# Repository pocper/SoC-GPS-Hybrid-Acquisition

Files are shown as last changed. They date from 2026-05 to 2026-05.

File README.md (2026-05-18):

# SoC-based GPS Receiver Implementation

本專案實作了一個基於 Intel Cyclone V SoC (DE10-Nano) 平台的 GPS 接收器系統，結合了自製的 MAX2769 RF 前端模組、FPGA 硬體加速器以及 HPS 控制韌體。

## 目錄
- [SoC-based GPS Receiver Implementation](#soc-based-gps-receiver-implementation)
  - [目錄](#目錄)
  - [1. 系統架構 (System Architecture)](#1-系統架構-system-architecture)
  - [2. 目錄導覽 (Repository Structure)](#2-目錄導覽-repository-structure)
  - [3. 開發環境配置 (Development Setup)](#3-開發環境配置-development-setup)
  - [4. 硬體接線與安全須知 (Hardware Connection)](#4-硬體接線與安全須知-hardware-connection)
  - [5. 演算法架構與狀態機 (Alogorithm \& Finite State Machine)](#5-演算法架構與狀態機-alogorithm--finite-state-machine)
  - [6. 程式燒錄與執行順序 (Programming Sequence)](#6-程式燒錄與執行順序-programming-sequence)
  - [7. 運行結果與驗證 (Experimental Results)](#7-運行結果與驗證-experimental-results)
    - [7.1 測試設備 (Testing Equipment)](#71-測試設備-testing-equipment)
    - [7.2. 核心運算耗時對比 (Core Algorithm Performance)](#72-核心運算耗時對比-core-algorithm-performance)
    - [7.3 全系統定位效能與 TTFF 綜合對比 (System-Level Performance \& TTFF)](#73-全系統定位效能與-ttff-綜合對比-system-level-performance--ttff)
    - [7.4 觀測組 5 次獨立實測原始數據紀錄 (Raw Experimental Data)](#74-觀測組-5-次獨立實測原始數據紀錄-raw-experimental-data)
    - [7.5 系統定位與速度解算驗證 (PVT Verification)](#75-系統定位與速度解算驗證-pvt-verification)

## 1. 系統架構 (System Architecture)

<div align="center">
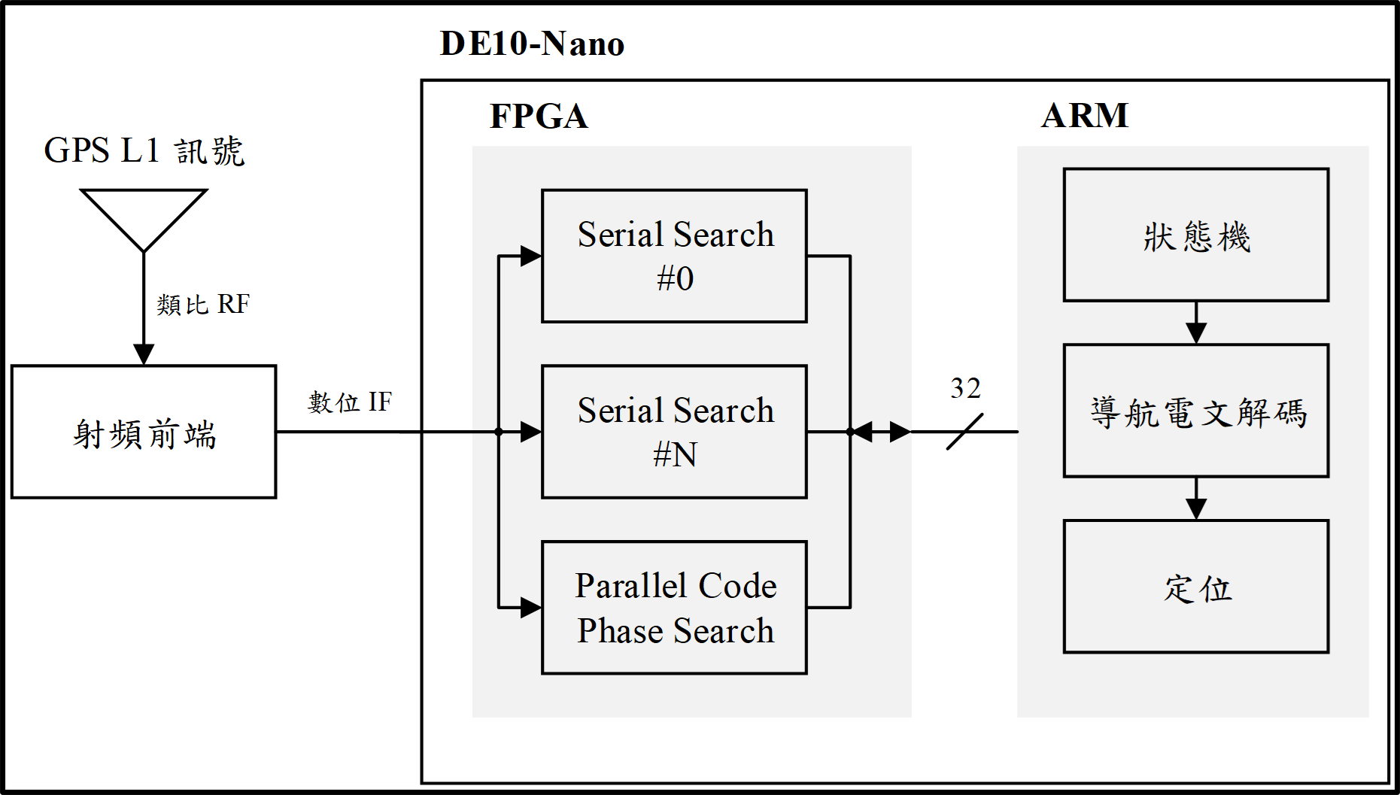
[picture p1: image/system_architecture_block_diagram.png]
系統架構
  
  <p style="margin-top: 10px;"><i>圖：系統架構圖</i></p>
</div>

本系統主要分為三大模組：
1. **RF Front-End**: 負責GPS L1訊號降採樣(Downsampling)。
2. **FPGA RTL**: 負責 Parallel Code Phase Search (PCPS) 加速。
3. **HPS Firmware**: 負責系統配置、追蹤運算與導航解算。

## 2. 目錄導覽 (Repository Structure)

1. [pcb frontend](pcb_frontend/) (Altium Designer Project)
    > 包含自製 MAX2769 RF 模組的設計檔案。
   - **硬體版本**: 目前推薦使用 **v3**。
   - **內容**: Altium Designer 專案、電路圖 (PDF)、製作與維修紀錄。

2. [rtl](rtl/) (Quartus Project)
    > 包含部署於 FPGA 端的 Verilog 原始碼與 Intel Quartus Prime 專案檔。
   - **核心模組**: 包含 Parallel Code Phase Search 與 Serial Search 之雙重訊號擷取架構。
   - **環境**: Intel Quartus Prime。
   - **重點**: 針對硬體並行化處理進行優化，減少擷取所需時間。

3. [firmware](firmware/) (Arm DS Project)
    > 負責執行於 HPS (ARM Cortex-A9) 之接收器韌體，透過 Avalon Bus 控制硬體暫存器。
   - [**hps_core/**](firmware/hps_core/)：**主要開發分支**。基於 ARM Compiler 6 (AC6) 環境開發，適用於個人電腦驗證。
   - [**hps_altera/**](firmware/hps_altera/)：**舊版相容分支**。基於 DS-5 (AC5) 環境開發，專供實驗室特定電腦驗證。

4. [matlab](matlab/) (MATLAB Project)
    > 包含 GPS 衛星訊號擷取演算法的模擬程式碼。
   - **主要功能**: 實現了平行碼相位搜尋演算法(Parallel Code Phase Search)。
   - **環境**: MATLAB。
   - **重點**: 作為演算法的功能模擬與設計標準，用於提前驗證演算法可行性，並作為後續 SoC 硬體開發時比對資料正確性的主要依據。

5. [document](docs/)
    > 存放專案相關的技術文件與操作指南。
   - [**how_to_apply_ds5.md**](docs/how_to_apply_ds5.md): **環境申請指南** (含 TSRI 資源、校園 DNS 正反查申請)。
   - [**emulator.md**](docs/emulator.md): **硬體操作手冊** (Agilent E4438C 與 Spirent GSS7000 操作流程)。
   - [**register_map.md**](docs/register_map.md): **暫存器映射表**。定義 HPS 與 FPGA  之間的通訊位址。
   - [**arm_core_initialization.md**](docs/arm_core_initialization.md): **ARM 核心與 RTOS 配置指南**。記錄 RTOS 環境下 Cortex-A9 時脈校正、GIC 映射與 RTX5 內核放寬執行緒上限之底層修正。

## 3. 開發環境配置 (Development Setup)

1. 硬體需求
   - **SoC開發板**: Terasic DE10-Nano (Cyclone V SoC)。
   - **射頻前端模組**: 自製 MAX2769 模組 (GPSR_frontend_v3)。
   - **訊號輸入源**: 
     1. **驗證配置**：經由同軸纜線連接至 Spirent GSS7000 訊號產生器。
     2. **實際配置 (未來)**：連接主動式 GPS 天線（需外接偏置電壓）。

2. 開發環境
   - **硬體開發**: Quartus Prime (建議 25.1 或以上版本) & Platform Designer。
   - **硬體/韌體函式庫**: Intel SoC EDS Embedded Development Suite (Version 20.1)。
   - **韌體開發環境**: Arm Development Studio (Version 2023.1) 或 DS-5 Altera Edition (Version 5.29.1)。
   - **即時作業系統**: CMSIS RTOS v2 (基於 Keil RTX5)。
   - **除錯終端**: PuTTY。

## 4. 硬體接線與安全須知 (Hardware Connection)

<div align="center">
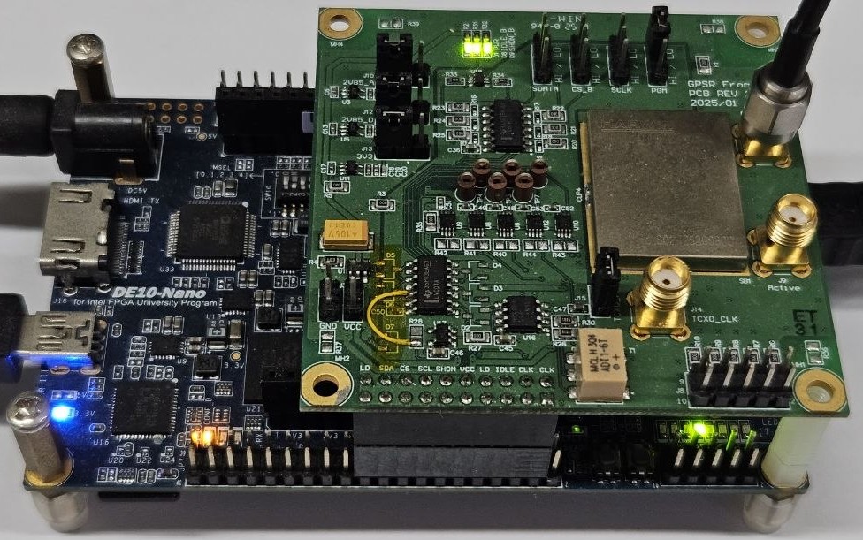
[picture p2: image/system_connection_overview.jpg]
系統接線總覽
  
  <p style="margin-top: 10px;"><i>圖：SoC GPS 接收器實驗驗證平台與硬體接線總覽</i></p>
</div>

1. **JTAG 偵錯**：將 mini-USB 連接至 DE10-Nano 的 **J13** 孔位並連接電腦 (用於 Quartus 燒錄及 DS-5 除錯)。
2. **UART 監控**：將 mini-USB 連接至 DE10-Nano 的 **J4**  孔位並連接電腦 (用於查看 HPS 端 UART Console 輸出結果)。
3. **RF 訊號輸入**：將 SMA Cable 連接至 Front-end 的 **J5** 孔位 (從GPS訊號產生器或天線提供 MAX2769 輸入訊號)。
4. **電源供應**：將 DC Power Cable(5V/2A) 連接至 DE10-Nano 的 **J14** 孔位，另一端連接插座。

> [!CAUTION]
> **重要上電順序提醒 (Critical Safety Warning)**
> 
> 在接通電源前，請務必確認上述 **1~3 項接線已全部連接穩固**。
> 
> **嚴禁在上電狀態下熱插拔 SMA 接頭**。由於上電瞬間可能產生瞬間脈衝 (Pulse) 或靜電，若此時才連接 SMA 接口，極易導致射頻前端 MAX2769 發生短路或因突波而燒毀。請遵循 **「先接線、後上電」** 的原則，拆卸時則反之。

## 5. 演算法架構與狀態機 (Alogorithm & Finite State Machine)

<div align="center">
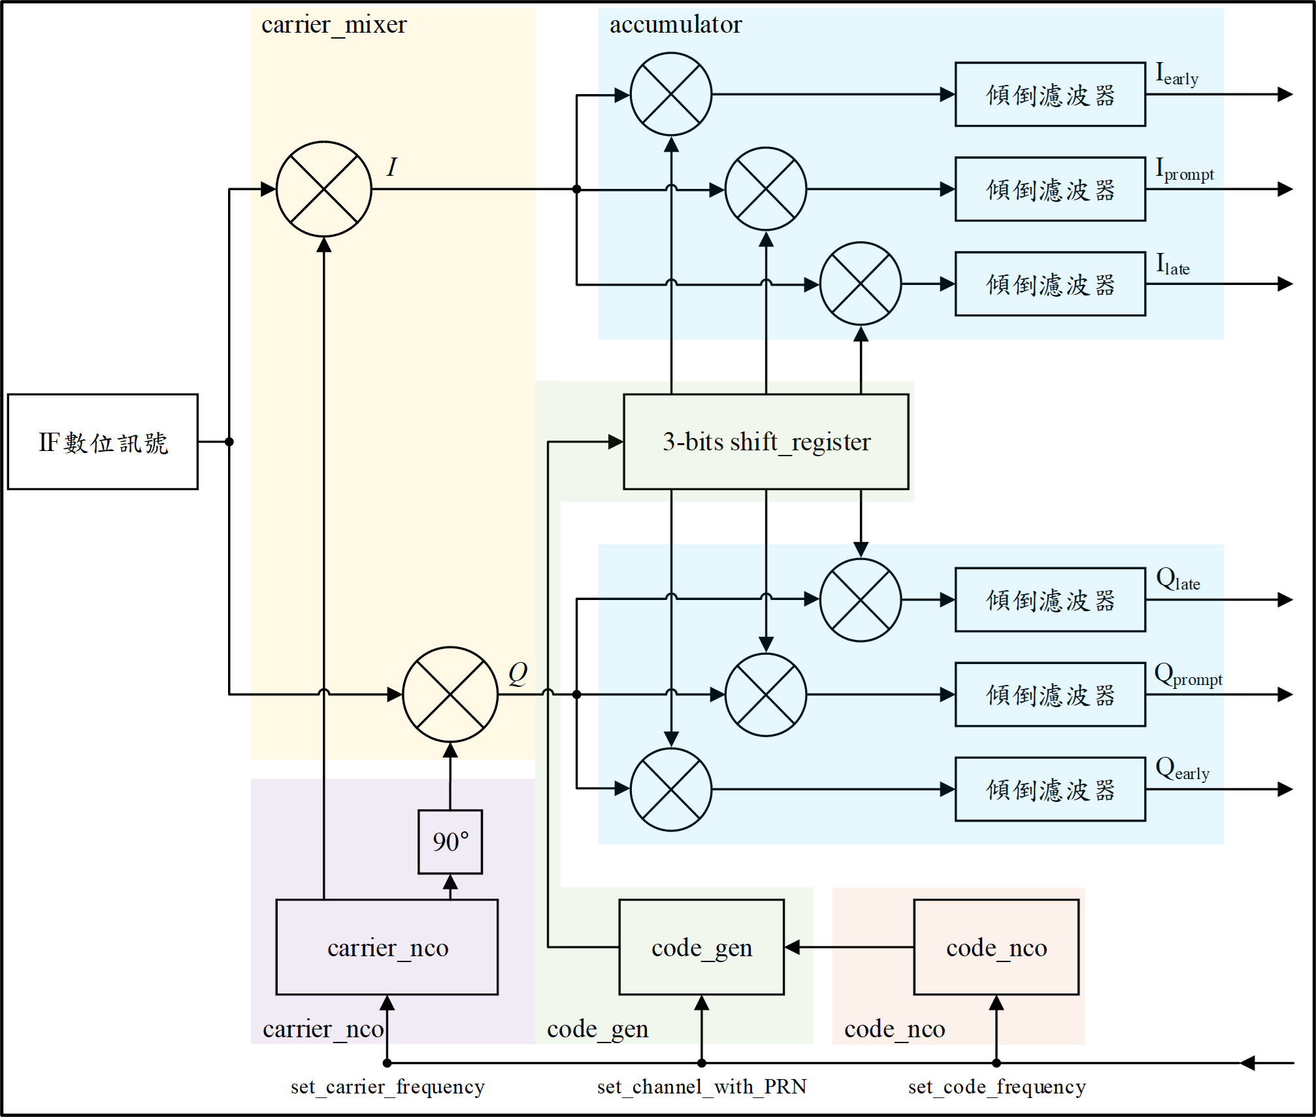
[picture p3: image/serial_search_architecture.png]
Serial Search 架構
  
  <p style="margin-top: 10px;"><i>圖：Serial Search 模組硬體架構圖</i></p>
</div>

<div align="center">
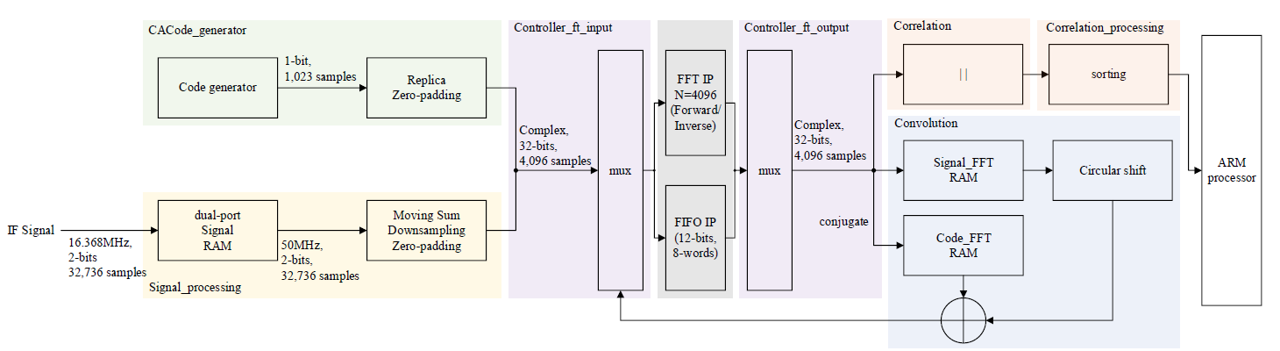
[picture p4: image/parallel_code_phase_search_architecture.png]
Parallel Code Phase Search 架構
  
  <p style="margin-top: 10px;"><i>圖：Parallel Code Phase Search 模組硬體架構圖</i></p>
</div>

<div align="center">

``` mermaid
graph LR
    classDef mainState fill:#EBF3FF,stroke:#2F80ED,stroke-width:2px,color:#000000,rx:8,ry:8;
    classDef startState fill:#1E293B,stroke:#0F172A,stroke-width:2px,color:#FFFFFF,rx:50,ry:50;

    OFF((OFF)):::startState -->|<span style='color:black;background:white;padding:2px_5px;border-radius:3px;'>Start</span>| Acquire([Acquire]):::mainState
    Acquire -->|<span style='color:black;background:white;padding:2px_5px;border-radius:3px;'>Acq. Success</span>| Confirm([Confirm]):::mainState
    Confirm -->|<span style='color:black;background:white;padding:2px_5px;border-radius:3px;'>Verify Pass</span>| Pull-In(["Pull-In"]):::mainState
    Pull-In -->|<span style='color:black;background:white;padding:2px_5px;border-radius:3px;'>Pull-In Pass</span>| Lock([Lock]):::mainState

    Acquire -->|<span style='color:black;background:white;padding:2px_5px;border-radius:3px;'>Acq. Fail</span>| OFF
    Confirm -->|<span style='color:black;background:white;padding:2px_5px;border-radius:3px;'>Verify Fail</span>| Acquire
    Pull-In -->|<span style='color:black;background:white;padding:2px_5px;border-radius:3px;'>Pull-In Fail</span>| Acquire
    Lock -->|<span style='color:black;background:white;padding:2px_5px;border-radius:3px;'>Lock Lost</span>| Pull-In
```

<p><i>圖：狀態機 - 原始架構</i></p>
</div>

<br/>

<div align="center">

``` mermaid
graph LR
    classDef mainState fill:#EBF3FF,stroke:#2F80ED,stroke-width:2px,color:#000000,rx:8,ry:8;
    classDef startState fill:#1E293B,stroke:#0F172A,stroke-width:2px,color:#FFFFFF,rx:50,ry:50;

    OFF((OFF)):::startState -->|<span style='color:black;background:white;padding:2px_5px;border-radius:3px;'>Parallel Search Done</span>| Refine([Refine]):::mainState
    Refine -->|<span style='color:black;background:white;padding:2px_5px;border-radius:3px;'>Refine Pass</span>| Pull-In(["Pull-In"]):::mainState
    Pull-In -->|<span style='color:black;background:white;padding:2px_5px;border-radius:3px;'>Pull-In Pass</span>| Lock([Lock]):::mainState

    Refine -->|<span style='color:black;background:white;padding:2px_5px;border-radius:3px;'>Refine Fail</span>| OFF
    Pull-In -->|<span style='color:black;background:white;padding:2px_5px;border-radius:3px;'>Pull-In Fail</span>| OFF
    Lock -->|<span style='color:black;background:white;padding:2px_5px;border-radius:3px;'>Lock Lost</span>| Pull-In
```
<p><i>圖：狀態機 - 混合架構</i></p>
</div>

## 6. 程式燒錄與執行順序 (Programming Sequence)

> [!IMPORTANT]
> **硬體相依性原則**：必須遵循「**先燒錄 FPGA，後燒錄 ARM**」的順序。若 FPGA 尚未配置完成便啟動 ARM 程式，CPU 會因存取未啟動的 Lightweight Bridge 實體位址而發生 Data Abort 當機。

1. **載入 FPGA 硬體邏輯 (Quartus)**：
   * 使用 **Quartus Programmer** 透過 JTAG (J13) 燒錄 `.sof` 檔案。
   * *詳細硬體編譯與 IP 配置細節請參閱 [rtl/README.md](rtl/README.md)。*

2. **執行 HPS 韌體程式 (DS-5 / Arm DS)**：
   * 根據您的環境開啟對應的整合開發環境（IDE），啟動 Debug 視窗並下載 `.axf` 執行檔至 RAM 運行：
        * **現代化環境 (Arm DS / AC6 工具鏈)** 👉 使用 **[firmware/hps_core/](firmware/hps_core/)** 專案。
        * **舊版相容環境 (DS-5 / AC5 工具鏈)** 👉 使用 **[firmware/hps_altera/](firmware/hps_altera/)** 專案。
      * *注意：首次除錯前請務必閱讀各韌體目錄下的 `README.md` 以完成 Debugger 腳本（preloader.ds）的掛載。*

3. **觀察除錯終端**：
   * 將電腦連接至 DE10-Nano 的 **J4 (USB-UART)** 埠，開啟 **PuTTY**（配置為 115200 波特率），即可即時觀測衛星搜尋等資訊。

## 7. 運行結果與驗證 (Experimental Results)

本專案透過硬體模擬器驗證接收器於不同場景下的定位效能。

### 7.1 測試設備 (Testing Equipment)
若需重現驗證結果，請參閱 **[docs/emulator.md](docs/emulator.md)** 之操作指引配置硬體環境。

| 實驗環境變數 (Parameter) | 實體軟硬體配置與參數 (Configuration Details) |
| :--- | :--- |
| **射頻訊號模擬器** | Spirent GSS7000 Multi-GNSS RF Signal Simulator |
| **測試衛星星座** | GPS L1 C/A (天空中包含 10 顆動態可見衛星) |
| **底層計時解析度** | ARM Cortex-A9 Private Timer (解析度: 1 ms) |
| **系統排程頻率** | CMSIS-RTOS v2 / Keil RTX5 (OS Tick Freuqency: 1000 Hz) |
| **統計實驗次數** | 5 次獨立重複實驗 (5 Trials per Power Level) |

### 7.2. 核心運算耗時對比 (Core Algorithm Performance)
下表展示了 SoC 平台在相同搜尋範圍下，執行不同基頻擷取演算法的純硬體運算耗時統計：

| 訊號擷取演算法 | 衛星數量 | 頻率搜索範圍 [kHz] | 總體執行時間 [ms] | 核心運算加速比 |
| :--- | :-----: | :---: | :---: | :---: |
| **直接搜尋法** <small>註1, 2</small> | 1 顆 | $0 \pm 10$ | 80,725.64 | 基準 (1.0x) |
| **碼相位平行搜尋法** | 1 顆 | $0 \pm 10$ | **4.07** | **19,834x** |
| **碼相位平行搜尋法** | 32 顆 | $0 \pm 10$ | **117.65** | **686x** |

<small>**註1**：直接搜尋法之執行時間為完整搜尋所有二維搜尋空間之最大耗時。若於搜尋空間中先行命中載波頻率及碼相位，程式會提早結束。</small>

<small>**註2**：直接搜尋法可透過在 FPGA 上配置多組實體硬體通道平行搜尋不同衛星，以降低總體執行時間。</small>

### 7.3 全系統定位效能與 TTFF 綜合對比 (System-Level Performance & TTFF)
本實驗測試共用相同之基頻硬體資源（Parallel Search 模組與 13 組序列硬體相關器通道），純粹透過 **ARM 韌體排程狀態機 (FSM) 的調度策略分流**，對比系統首次定位時間（Time To First Fix, TTFF）的實測結果：

   * **混合架構 (Parallel Code Phase Search + Serial Search)**：完整驅動 FPGA 內之 Parallel Code Phase Search 硬體加速模組進行全星座快速擷取，隨後動態將參數分派予 13 組序列硬體相關器（Serial Correlator）進行精細微調與追蹤。
   * **單一架構 (Serial Search)**：於軟體層面將 Parallel 加速器暫存器關閉，冷啟動後純依賴 13 組通道進行時域與頻域的逐點掃描。為了排除純韌體超時輪詢變因、專注比對硬體搜尋物理速度，此模式下開機**預先指派模擬器中存在的 10 顆存在衛星號碼（指定 PRN）**。

| 模擬器功率 [dBm] | 架構 | 4 顆衛星達成鎖定之耗時 [s] <br>(範圍 / 平均值) | 首次定位時間 [s] <br>(範圍 / 平均值) | **硬體搜尋加速比** |
| :---: | :---: | :---: | :---: | :---: |
| **-115** | 單一 | 19.073 ~ 28.095 (**23.902**) | 51.233 ~ 60.218 (**55.570**) | 基準 (1.0x) |
| | 混合 | 1.122 ~ 3.206 (**2.139**) | 26.085 ~ 39.069 (**31.465**) | **11.17x 加速** |
| **-120** | 單一 | 19.143 ~ 25.171 (**21.554**) | 46.075 ~ 56.133 (**50.134**) | 基準 (1.0x) |
| | 混合 | 1.152 ~ 2.253 (**1.943**) | 27.234 ~ 38.067 (**33.915**) | **11.09x 加速** |
| **-125** | 單一 | 25.234 ~ 32.026 (**29.351**) | 47.057 ~ 74.192 (**61.511**) | 基準 (1.0x) |
| | 混合 | 28.180 ~ 84.115 (**50.725**) | 80.044 ~ 156.029 (**108.885**) | **註1** |
| **-130** | 單一/混合 | — | — | **註2** |

<small>**註1**：在 `-125 dBm` 下，混合架構因頻率觀測頻寬較寬（500 Hz vs. Serial 125 Hz），致使單一頻率分度（Bin）內累積之總雜訊功率較高。在弱訊號下，真實訊號極易低於硬體偵測門檻而遭誤判，狀態機須反覆驗證，故鎖定耗時拉長。</small>

<small>**註2**：訊號功率降至 `-130 dBm` 時，在當前配置之積分時間（Parallel Code Phase Search: 2 ms / Serial: 1 ms）限制下，相關峰值已無法超越雜訊基底，故不論何種調度模式皆無法達成穩定鎖定。</small>

> [!NOTE]
> **為什麼冷啟動 (Cold Start) 解讀導航電文至少需要 18 秒？**
> * **導航電文傳輸速率**：固定只有 50 bps（每秒 50 bits）。
> * **必備資料框 (Data Frame)**：定位解算前，韌體必須完整取得子框架 (Subframe) #1、#2 與 #3。
> * **解讀時間**：每個子框架長度為 300 bits（耗時 6 秒），連續下載並解讀完這三個必備子框架（共 900 bits），**至少需要 18 秒的連續傳輸時間**（尚未包含冷啟動後捕捉前導字元以達成框架同步的時間差）。

### 7.4 觀測組 5 次獨立實測原始數據紀錄 (Raw Experimental Data)
若需核對或重現統計大表中的範圍區間，可展開下方摺疊面板檢視各組 Run 1 ~ Run 5 的詳細觀測值：

<details>
<summary><b>點擊展開：查看混合架構 5 次獨立實測詳細數據紀錄</b></summary>

| 模擬器輸出功率 [dBm] | 4 顆衛星達成鎖定之耗時 [s] <br> (Run 1 / 2 / 3 / 4 / 5) [平均值] | 首次定位時間 (TTFF) [s] <br> (Run 1 / 2 / 3 / 4 / 5) [平均值] |
| :---: | :--- | :--- |
| **-115** | 2.134 / 3.206 / 1.122 / 3.084 / 1.151 <br> **[Mean: 2.139]**  | 26.085 / 39.069 / 29.065 / 36.035 / 27.073 <br> **[Mean: 31.465]** |
| **-120** | 2.019 / 2.062 / 2.253 / 2.229 / 1.152 <br> **[Mean: 1.943]**  | 34.078 / 37.055 / 38.067 / 33.142 / 27.234 <br> **[Mean: 33.915]** |
| **-125** | 28.180 / 44.113 / 60.064 / 37.154 / 84.115 <br> **[Mean: 50.725]** | 80.044 / 98.198 / 97.006 / 113.242 / 156.029 <br> **[Mean: 108.885]** |
</details>
<br/>
<details>
<summary><b>點擊展開：查看單一架構 5 次獨立實測詳細數據紀錄</b></summary>

| 模擬器輸出功率 [dBm] | 4 顆衛星達成鎖定之耗時 [s] <br> (Run 1 / 2 / 3 / 4 / 5) [平均值] | 首次定位時間 (TTFF) [s] <br> (Run 1 / 2 / 3 / 4 / 5) [平均值] |
| :---: | :--- | :--- |
| **-115** | 23.033 / 26.176 / 19.073 / 28.095 / 23.131 <br> **[Mean: 23.902]** | 57.134 / 56.106 / 53.161 / 60.218 / 51.233 <br> **[Mean: 55.570]** |
| **-120** | 23.083 / 25.171 / 20.245 / 19.143 / 20.129 <br> **[Mean: 21.554]** | 56.133 / 46.075 / 53.237 / 48.005 / 47.221 <br> **[Mean: 50.134]** |
| **-125** | 32.026 / 25.234 / 31.201 / 27.118 / 31.176 <br> **[Mean: 29.351]** | 61.137 / 47.057 / 65.145 / 74.192 / 60.025 <br> **[Mean: 61.511]** |
</details>
<br/>

### 7.5 系統定位與速度解算驗證 (PVT Verification)

本研究在系統鎖定穩態後進行定量分析，以驗證底層基頻演算法之絕對正確性，其實驗配置與統計要點如下：

* **PVT 更新率**：**10 Hz**（每 100 ms 解算一次）。
* **統計樣本數量**：定位成功期間，連續紀錄 **1,259 筆 有效觀測樣本**。

| 效能參數 | 模擬器真實值 | 接收機實測平均值 | 實測誤差與統計指標 |
| :--- | :---: | :---: | :--- |
| **ECEF X 軸位置** | `+6378137.000 m` | `+6378135.534 m` | **1.466 m** (MAE)  |
| **ECEF Y 軸位置** | `0.000 m` | `-0.342 m` | **0.342 m** (MAE)  |
| **ECEF Z 軸位置** | `0.000 m` | `-0.245 m` | **0.245 m** (MAE)  |
| **平均定位誤差** | `0.000 m` | — | **6.492 m**  (3D 空間平均定位誤差) |
| **定位穩定度 (SD)** | `0.000 m` | — | **4.620 m** |
| **最大定位誤差** | — | — | **41.799 m** |
| **參與定位衛星顆數** | `10 顆` | `10 顆` | 訊號追蹤階段無失去鎖定 |
| **ECEF X 軸速度 ($V_x$)** | `0.000 m/s` | — | **0.633 m/s** (RMSE) |
| **ECEF Y 軸速度 ($V_y$)** | `0.000 m/s` | — | **0.245 m/s** (RMSE) |
| **ECEF Z 軸速度 ($V_z$)** | `0.000 m/s` | — | **0.331 m/s** (RMSE) |
| **平均速度誤差** | `0.000 m/s` | — | **0.756 m/s** (3D 空間平均速度誤差) |

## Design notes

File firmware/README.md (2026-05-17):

# GPSR - ARM HPS Bare-metal Implementation

本專案包含兩套針對不同編譯器與 IDE 環境所開發的 GPS 接收器 SoC 實作版本。兩者皆基於 **Intel Cyclone V SoC (DE10-Nano)** 硬體平台。

## 專案目錄說明

| 目錄名稱 | 建議環境 (IDE / Compiler) | 專案定位 | 取得方式 |
| --- | --- | --- | --- |
| **hps_core/** | **Arm DS / AC6** | **主要開發分支**。<br/>包含最新演算法、雙信號加速研究及完整專案結構。 | 須依據 `apply.md` 提出申請。 |
| **hps_altera/** | **DS-5 / AC5** | **舊版相容分支**。<br/>適用於學術單位舊型電腦環境，具備特定的 Makefile 修正機制。 | 僅限於特定配置之實驗室電腦使用。 |

---

## 核心環境差異與選擇指南

### 1. hps_core (Primary)

* **適用對象**：個人筆電或已安裝最新 **Arm Development Studio (Arm DS)** 的環境。
* **技術特點**：使用 **Arm Compiler 6 (LLVM)**，編譯效率較高且支援最新的 C 語言標準。
* **權限說明**：由於包含核心研究代碼，存取前請參考 **[how_to_apply_ds5.md](../docs/how_to_apply_ds5.md)** 完成申請程序。

### 2. hps_altera (Legacy Support)

* **適用對象**：僅能使用 **DS-5 Altera Edition (v5.29.1)** 或 **Arm Compiler 5 (AC5)** 的開發者。
* **技術特點**：針對 AC5 的語法嚴謹度進行了調校，並手動禁用了自動 Makefile 生成以避開編譯器 Bug。
* **重要備註**：本目錄不含源碼原始檔，匯入後須先執行從 `hps_core` 搬移檔案的手動同步動作。

---

## 快速上手 (Getting Started)

1. **環境確認**：檢查您的開發電腦安裝的是 **Arm DS** 還是 **DS-5 Altera Edition**。
2. **查閱文件**：
* 若進入 `hps_core`，請先閱讀該目錄下的 `README.md` 了解功能架構。
* 若進入 `hps_altera`，請務必詳閱其 `README.md` 中的 **[Step 0] 檔案複製說明**，否則專案將無法編譯。

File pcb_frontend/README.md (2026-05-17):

# Front-End (GNSS RF Module)

本文檔記錄了基於 **MAX2769** 的 GNSS 前端（Front-End）開發過程，包含從 v1 到 v3 的硬體迭代細節、已知問題與解決方案。

## 開發工具與關鍵零件

* **PCB 軟體**: Altium Designer
* **核心晶片 (MAX2769)**:
  * **v1, v3**: 使用 `MAX2769ETI/V+` (已停產)
  * **v2**: 使用 `MAX2769BETI/V+` ([Mouser 連結](https://mou.sr/4noLCAx))

* **重要提醒**: Sign/Mag 訊號是在 Clock 的上升緣變化，因此建議在 Clock 下降緣進行採樣，以確保資料穩定([datasheet - MAX2769](https://www.mouser.tw/datasheet/3/1014/1/MAX2769B.pdf))。
* 電路圖:
  * [Schematic - Version 1](./v1/GPSR_frontend_v1.pdf)
  * [Schematic - Version 2](./v2/GPSR_frontend_v2.pdf)
  * [Schematic - Version 3](./v3/GPSR_frontend_v3.pdf) 

## 版本更迭 (Version History)

* **Version 0**: 使用 MAX2769 Evaluation Boards（包含燒錄 config 板與 front-end 板）。
* **Version 1**: 依照 MAX2769 datasheet 標準電路設計。
* **Version 2**: 根據 v1 進行改版，優化屏蔽、抗干擾與時鐘同步設計。
* **Version 3**: 解決輸出電壓位準、訊號 ringing 及電源相容性問題。

| 版本 | v1 | v2 | v3 |
| :--: | :--: | :--: | :--: |
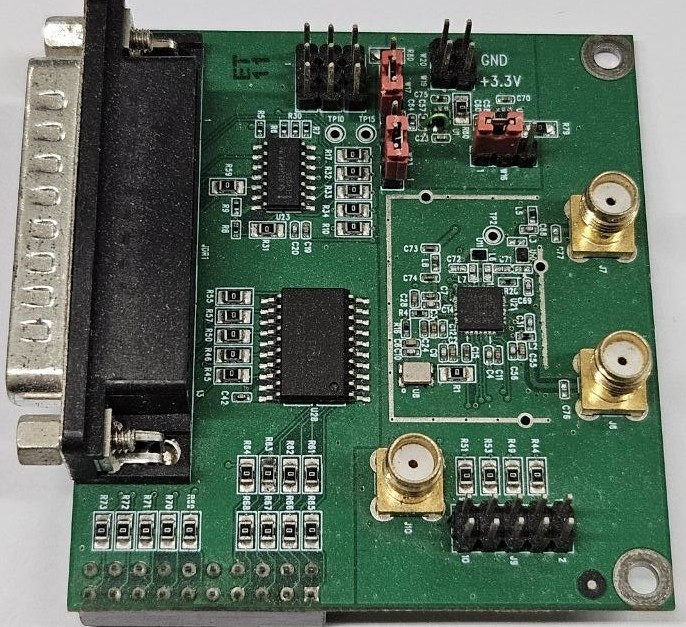
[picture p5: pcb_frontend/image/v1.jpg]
image_v1
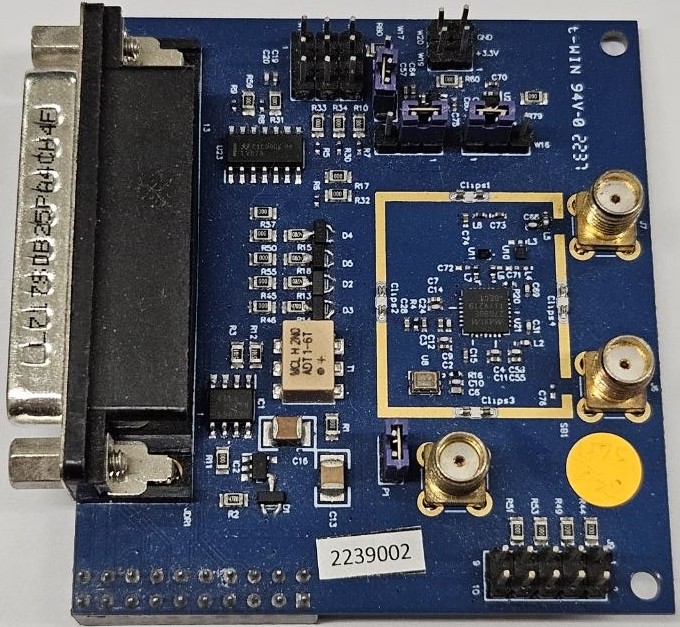
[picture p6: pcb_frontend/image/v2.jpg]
image_v2
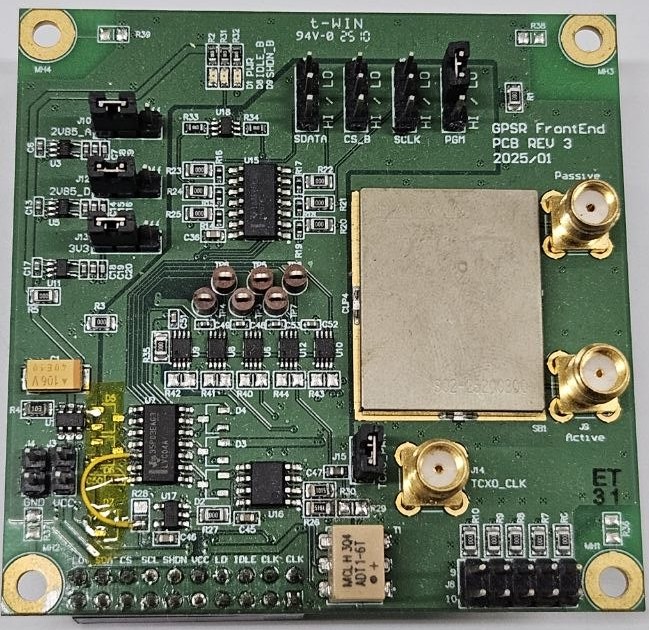
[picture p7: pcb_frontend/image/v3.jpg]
image_v3
|照片||||

## 生產與庫存記錄

* **最後更新日期**: 2026/05/11

| 版本 | v0  | v1  | v2 | v3 |
| --- | --- | --- | ---| --- |
| 原始生產數量 | 1+1 | 10  | 10 | 10 |
| 現存/可用數  | 1+1 | 2 | 10 | 9 |
| 交期 | - | - | 2022/09/16 | 2025/03/14 |

*備註：v0 係因原廠開發板配置；v1~v3 原始生產均為 10 片，數量減少源於研發過程損耗。*

---

## 相對前版本的更新 (Key Updates)

### v1 → v2

* **電路簡化**: 移除 I/Q Buffer (SN74ACT241DW)。
* **抗干擾**: 增加屏蔽框 (Shielding case)，減少外部 EMI 影響。
* **時鐘系統**:
  * TCXO 由 IT5305BE 更換為 **D32G-016.368M**。
  * 增加時鐘緩衝電路 (ADTI-6T+, MAX961ESA+, SN74LV1T34DBVRG4)。
* **訊號與保護**:
  * 更換濾波器為 SF14-1575F5UUA1。
  * 增加 GPIO 位準保護二極體 (BAT54STA)。
  * 核心晶片更換為 **MAX2769BETI+T**。

* **多天線同步設計**:
  * 增加 Header (P1) 與 SMA (J10) 設計。雙天線模式下，第二塊板需斷開 Header 並透過 J10 共享第一塊板的時鐘，以達成採樣同步。

* **特殊版本**: 10 片中透過 U11 濾波器區分：
  * **6 片 (2239000~2239005)**: GPS 頻段 (RSF-1575.420)。
  * **4 片 (2239006~2239009)**: GLONASS 頻段 (RSF-1582.400)。

### v2 → v3

* **控制介面**: 移除 D-Connector 25，改由 DE10-Nano 進行 SPI 設定。
* **電源增強**:
  * 支援 **3.3V / 5V 電壓輸入**。
  * 增加防反接保護電路 (U1A/U1B)。
  * 增加獨立 LDO (MAX8510) 穩定供電給 TCXO、Buffer 與保護電路。

* **訊號品質優化**:
  * 解決 I/Q 輸出電壓偏低 (2.85V → 3.3V) 與 ringing 問題，增加輸出 Buffer (SN74LVC1404 / SN74LVC04)。
  * 增加 GPIO 20-pin 磁珠濾波。

* **狀態顯示**: 增加指示燈 (PWR / IDLE_B / SHDN_B)，**三燈全亮**方可正常運作。

## 已知問題 (Hardware Bugs)

### v1

* PCB 原始檔案遺失。
* **電源限制**: 僅支援 3.3V 輸入，輸入 5V 會直接損毀板子。

### v2 (FAILED 版本)

* **封裝錯誤**: BAT54STA 封裝與零件不符，需人工跳線修正。
* **機構問題**: 鎖孔位置偏離，無法與 DE10-Nano 對齊。
* **接地缺陷**: MAX2769 Pin 29 (EP) 與濾波器 Pin 3 未接至 AGND，影響散熱與 EMI。
* **供電不足**: TCXO 實測僅 2.85V（應為 3.3V），導致採樣異常。
* **邏輯錯誤**: LD_OUT 未連接至 MAX2769。
* **高昂成本**: 時鐘緩衝電路零件昂貴（近 NT$ 1,000）且僅解決 CLK 訊號。

### v3

* **保護電路風險**: BAT54STA 在持續過壓時會將電流拉向 VCC/GND，可能導致整板電源軌毀損。
* **高昂成本**: 時鐘緩衝電路零件昂貴（近 NT$ 1,000）且僅解決 CLK 訊號。
* **數位失真**: GPIO 上的磁珠會導致高速數位訊號（CLK_OUT、I/Q 等）嚴重失真。

## 解決辦法 (Fixes)

### v3 必要的硬體修正步驟

1. **解決訊號失真**:
   * 將磁珠 **FB13, FB15, FB17** 更換為 **0Ω (0402)** 電阻。
   * 直接 **移除** 磁珠 FB1, FB2, FB4, FB8。

2. **邏輯與跳線**:
   * 移除電阻 **R28, R29**。
   * 跳線：連接 **U7 (SN74LVC04ADR) pin 12** 至 **R28 pin 2**。
   * C54, R45 不須焊接。

3. **成本降低建議**:
   * 若不需特定時鐘緩衝，建議移除 T1, U16, U17 及其周邊電路。

---

## GPIO 定義表
> [!NOTE]
> **注意**: v1, v2 版本請務必使用 **PIN 2 (CLK_OUT)** 作為主要時鐘源，避免使用經過 Buffer 後失真的 PIN 19。

| PIN | 變數 | 用途 | 來源地 (MAX2769) | 說明 |
| --- | --- | --- | --- | --- |
| 1 | I+ | i_sign | PIN 21 (I1_OUT) |  |
| 2 | CLK_OUT | CLK | PIN 16 (CLK_OUT) | v1, v2 主要時鐘源 |
| 3 | I- | i_mag | PIN 20 (I0_OUT) |  |
| 5 | Q+ | q_sign | PIN 17 (Q1_OUT) |  |
| 6 | IDLE_B_IN | IDLE | PIN 24 (IDLE) | 1: 工作, 0: 待機 |
| 7 | Q- | q_mag | PIN 18 (Q0_OUT) |  |
| 8 | LOCK_DET | LD | PIN 6 (LD) | 1: MAX2769 clk PLL 鎖定 |
| 12 | SHDNB_IN | SHDNE | PIN 7 (SHDNE) | 1: 開啟, 0: 關閉晶片 |
| 14 | SCLK_IN | SCLK | PIN 9 (SCLK) |  |
| 16 | CS_B_IN | CS_B | PIN 10 (CS_B) | 低電位有效 |
| 18 | D_IN | SDATA | PIN 8 (SDATA) |  |
| 19 | CLK | CLK  | PIN 16 (CLK_OUT)  | v3 主要時鐘源 |

---

## 製作與廠商資訊 (Manufacturing)

本專案硬體委託 **兆發科技 (T-Win)** 製作，包含 PCB Layout 與 SMT 上件。

* **廠商網站**: [兆發科技官方網頁](https://www.t-win.com.tw/Index-new(C).html)
* **參考費用**:
  * **v2 版本 (10片)**: 約 **NT$ 80,000 - 90,000** 級距。
  * **v3 版本 (10片)**: 約 **NT$ 110,000 - 120,000** 級距。
* **備註**: 上述價格包含 Layout、製造、零件採購與組裝。實際報價會隨晶片市場波動，詢價時請提供本專案之 Gerber 檔與 BOM 表。

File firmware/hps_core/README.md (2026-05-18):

# GPSR - ARM HPS Bare-metal Implementation
本專案實作於 **Intel Cyclone V SoC (DE10-Nano)** 平台，核心基於 **CMSIS RTOS v2** 進行任務排程，並透過 HPS 驅動 FPGA 端的 GPS 訊號擷取加速電路。

## 目錄
- [GPSR - ARM HPS Bare-metal Implementation](#gpsr---arm-hps-bare-metal-implementation)
  - [目錄](#目錄)
  - [1. 開發環境 (Prerequisites)](#1-開發環境-prerequisites)
  - [2. 專案架構與配置 (Project Structure)](#2-專案架構與配置-project-structure)
    - [核心檔案與配置](#核心檔案與配置)
    - [模組說明 (SRC / INC)](#模組說明-src--inc)
    - [軟體組件配置 (RTE Configuration)](#軟體組件配置-rte-configuration)
      - [HPS 底層暫存器與時脈校正說明](#hps-底層暫存器與時脈校正說明)
  - [3. 系統架構 (System Architecture)](#3-系統架構-system-architecture)
    - [硬體加速層 (FPGA)](#硬體加速層-fpga)
    - [軟體控制層 (CMSIS RTOS v2)](#軟體控制層-cmsis-rtos-v2)
    - [系統交互數據流 (Data Flow Diagram)](#系統交互數據流-data-flow-diagram)
  - [4. 如何執行 (Getting Started)](#4-如何執行-getting-started)
    - [Step 1: 匯入專案 (Import Project)](#step-1-匯入專案-import-project)
    - [Step 2: 編譯專案 (Build Project)](#step-2-編譯專案-build-project)
    - [Step 3: 硬體連線與除錯配置 (Debug Configuration)](#step-3-硬體連線與除錯配置-debug-configuration)
    - [Step 4: 顯示輸出資訊 (Monitoring)](#step-4-顯示輸出資訊-monitoring)
  - [5. 硬體資源配置 (Hardware Resource Allocation)](#5-硬體資源配置-hardware-resource-allocation)
    - [5.1 暫存器映射與基底位址 (Register Map \& Base Address)](#51-暫存器映射與基底位址-register-map--base-address)
    - [5.2 執行緒清單 (Thread List)](#52-執行緒清單-thread-list)
    - [5.3 中斷向量映射 (Interrupt Mapping)](#53-中斷向量映射-interrupt-mapping)
  - [6. 技術實作細節 (Implementation Details)](#6-技術實作細節-implementation-details)
    - [6.1 軟體架構與執行緒 (Software Architecture \& Threads)](#61-軟體架構與執行緒-software-architecture--threads)
    - [6.2 平行碼相位搜尋流程 (Parallel Code Phase Search Flow)](#62-平行碼相位搜尋流程-parallel-code-phase-search-flow)
    - [6.3 數據流與狀態轉移 (Data Flow \& FSM)](#63-數據流與狀態轉移-data-flow--fsm)
      - [6.3.1 狀態機比較圖 (State Machine Comparison)](#631-狀態機比較圖-state-machine-comparison)
      - [6.3.2 邏輯說明](#632-邏輯說明)
    - [6.4 訊號擷取模式配置 (Acquisition Mode Configuration)](#64-訊號擷取模式配置-acquisition-mode-configuration)
  - [7. 已知問題與解決方案 (Known Issues)](#7-已知問題與解決方案-known-issues)
  - [專案參考 (References)](#專案參考-references)
    - [硬體與底層技術手冊](#硬體與底層技術手冊)
    - [開源框架與學術文獻](#開源框架與學術文獻)

## 1. 開發環境 (Prerequisites)
* **硬體平台**: Terasic DE10-Nano (Cyclone V 5CSEBA6U23I7)。
* **開發環境**: ARM Development Studio (DS) Golden Edition (Version 2023.1)。
* **開發套件**: SoC FPGA Embedded Development Suite Standard Edition (Version 20.1)。
* **作業系統**: CMSIS RTOS v2 (基於 Keil RTX5)。
* **編譯器**: ARM Compiler 6 (AC6)。
* **終端機軟體**: PuTTY (用於透過 UART 觀察系統輸出與 HPS 狀態)。
* **硬體需求**: 需先透過 Quartus 編譯並產生 `.rbf` 檔案載入 FPGA，確保 HPS 可透過 Lightweight HPS-to-FPGA Bridge 存取暫存器。

## 2. 專案架構與配置 (Project Structure)

本專案採模組化設計，將硬體底層驅動、GPS 核心演算法與 RTOS 系統配置分離。

### 核心檔案與配置

* **`DE10_serial_parallel/main.c`**: 程式進入點，負責 線程(Threads)初始化、硬體周邊配置及啟動 CMSIS RTOS v2 核心任務。
* **`DE10_serial_parallel/DE10_serial_parallel.rteconfig`**: ARM Development Studio 的運行環境配置文件，定義組件相依性。
* **`DE10_serial_parallel/config_hardware/`**: 存放偵錯配置檔 (`.launch`)，記錄 JTAG 連線參數與應用程式下載設定。
* **`bootloader/preloader.ds`**: ARM DS 除錯腳本，用於引導硬體初始化。該腳本會加載並執行同目錄下的 **`u-boot-spl`**，完成 HPS 側的 UART、DDR 記憶體及多功能引腳 (I/O Multiplexing) 的初始化，確保應用程式能正確下載至 RAM 運行。

### 模組說明 (SRC / INC)

檔案依功能劃分為以下四大模組：

| 模組類別 | 包含檔案 (實作/標頭檔) | 說明 |
| --- | --- | --- |
| **系統與通訊** | `uart.c`, `display.c`, `message.c` | 負責 HPS UART 偵錯輸出、數據格式封裝及資訊顯示。 |
| **硬體驅動層** | `max2769.c`, `altera_avalon_spi.c`, `parallel_search.c`  | 處理 RF 前端 (MAX2769) 配置、Avalon Bus 通訊及**平行搜尋硬體加速器**控制。 |
| **GPS 核心演算法** | `tracking.c`, `measure.c`, `ephemeris.c`, `position.c` | 實現衛星信號追蹤、虛擬距離測量、星曆解析及定位運算 (PVT)。 |
| **導航計算工具** | `DOP.c`, `pseudorange.c`, `allocate.c`, `time.c` | 處理幾何精度因子計算、時間同步及衛星通道分配邏輯。 |

### 軟體組件配置 (RTE Configuration)

匯入專案後，請雙擊打開 `.rteconfig` 檔案，確保 **Manage Run-Time Environment** 視窗中已正確勾選以下組件，這對於 **ARM Compiler 6 (AC6)** 的編譯至關重要：

| 類別 (Category) | 組件名稱 (Component) | 變體 (Variant) | 實測版本 (Version) | 說明 |
| --- | --- | --- | --- | --- |
| **ARMCA9** | - | - | **1.1.0** | 提供 Cortex-A9 核心基礎定義。 |
| **CMSIS** | **CORE** | - | **6.1.0** | 提供 Cortex-A9 核心基礎定義。 |
| **CMSIS** | **OS Tick (API) -> Private Timer** | - | **1.0.2** | 提供 RTOS 系統時間，確保任務切換與延時運算之精準度。 |
| **CMSIS** | **RTOS2 (API) -> Keil RTX5** | **Source** | **5.9.0** | 核心任務調度器，負責多執行緒並行運作。 |
| **CMSIS-Compiler** | **STDIN/STDOUT (API) -> Custom** | - | **1.1.0** | 將 `printf` 重新導向至 `uart.c`。 |
| **Device** | **IRQ Controller (API) -> GIC** | - | **1.2.0** | 管理來自 FPGA 端之 **FPGA_IRQ0/1** 中斷。 |
| **Device** | **Startup** | - | **1.2.0** | 包含啟動引導、Scatter file 與 **MMU 配置**。 |

#### HPS 底層暫存器與時脈校正說明

本專案在 ARM DS / DS-5 環境下，已針對 CMSIS 產生的預設 `ARMCA9` 核心配置進行了關鍵修正（包含 GIC/Timer 實體位址重對映、925 MHz 4分頻時脈校正、關閉 MMU 以及鎖定 `-O0` 編譯優化）。

* **完整相容性原理與核對清單**：請參閱詳細技術指南 [docs/arm_core_initialization.md](../../docs/arm_core_initialization.md)
* *註：相關修正已完好儲存於本專案的 `INC/` 與設定檔中，匯入後自動覆蓋預設值，此文件僅供原理核對使用。*

## 3. 系統架構 (System Architecture)
本系統將 GPS 接收器的處理邏輯分為「即時韌體控制」與「硬體運算加速」兩大部分：

### 硬體加速層 (FPGA)

* **Serial Search**: 負責多通道的關聯運算（Correlators）與衛星追蹤。
* **Parallel Code Phase Search**: 負責快速擷取衛星訊號，大幅縮短首次定位時間 (TTFF)。
* **MAX2769 SPI 控制**: 負責 RF 前端參數設定。

### 軟體控制層 (CMSIS RTOS v2)

* **Task Scheduling**: 包含衛星搜尋任務、追蹤環路任務、以及數據遙測傳輸任務。
* **Event Handling**: 利用 RTOS Event Flags 或 Semaphores 響應硬體中斷。

### 系統交互數據流 (Data Flow Diagram)
本專案之軟硬體交互邏輯參考自經典的開源導航專案 Namuru GPS，並針對 Cyclone V HPS 進行了移植與優化：

<div align="center">
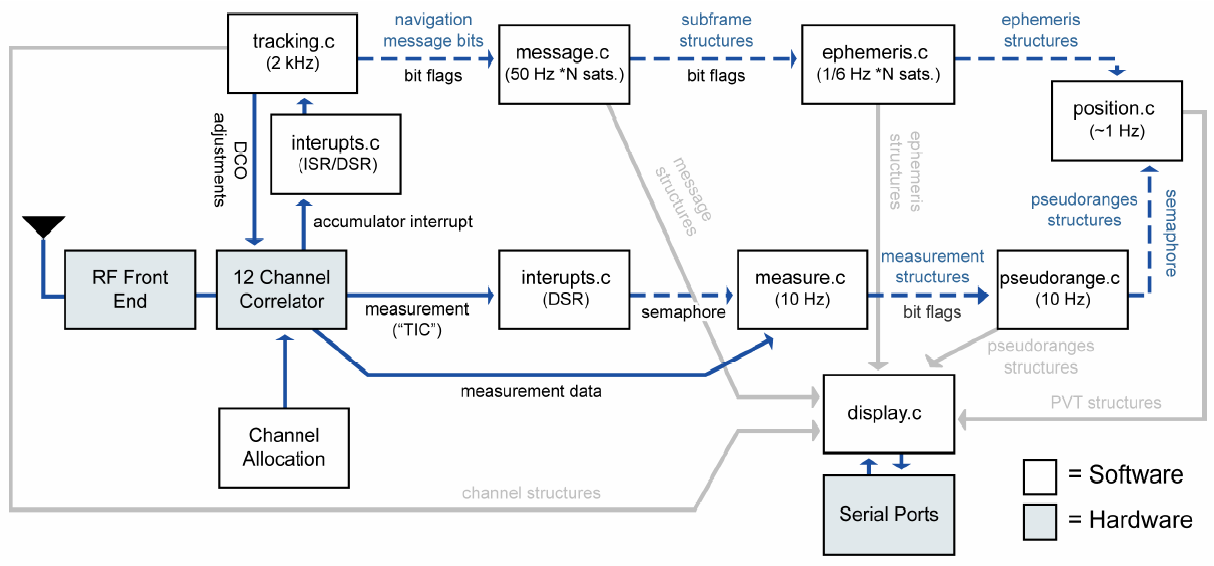
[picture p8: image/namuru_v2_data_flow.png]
Namuru V2 數據流圖
  
  <p><i>圖：Namuru V2 框架之數據流圖（圖片來源：<a href="https://www.semanticscholar.org/paper/The-Namuru-V2-open-source-GNSS-receiver-project-Mumford-Akos/fdfd5889722f786af1faafd68cfd5bef9aa55d25" target="_blank">The Namuru V2 Project</a>）</i></p>
</div>

## 4. 如何執行 (Getting Started)
本節說明如何將專案匯入 **ARM Development Studio**、編譯並透過 **USB-Blaster II** 進行硬體偵錯。

### Step 1: 匯入專案 (Import Project)

1. 啟動 **ARM Development Studio** (Golden Edition)。
2. 點選選單 `File` -> `Switch Workspace` -> `firmware/hps_core`。
3. 點選選單 `File` -> `Import...`。
4. 選擇 `General` -> `Existing Projects into Workspace`，並點選 `Next`。
5. 在 `Select root directory` 中點選 `Browse..`，路徑切換至 `firmware/hps_core/DE10_serial_parallel` 目錄後點選 `選擇資料夾`。
6. 在 `Projects` 清單中勾選 `DE10_serial_parallel`，最後點選 `Finish`。

### Step 2: 編譯專案 (Build Project)

1. 點選選單 `Project` -> `Build All`。
2. **編譯檢查**：
   * 出現 **Warnings** 通常為編譯器優化建議，尚可接受。
   * 若出現 **Errors** 則代表 `.axf` 執行檔未成功生成，請檢查 Include 路徑或 CMSIS 庫配置。

### Step 3: 硬體連線與除錯配置 (Debug Configuration)

1. **硬體連結**：
   * 使用一條 **Mini USB 線** 連接 DE10-Nano 上的 **USB-Blaster II 埠** (J13) 與開發電腦。
   * 無需外接額外的偵錯器硬體，該連線同時提供 JTAG 偵錯與 UART 通訊功能。

2. **硬體檢查**：
   * **指撥開關 (MSEL)**：請確保DE10-Nano 上的 **MSEL[4:0]** 開關設定為 `01010` (FPP 模式)以允許 HPS 透過 FPGA Manager 配置硬體。
   * **FPGA 載入狀態**：在啟動 DS 偵錯前，請務必透過 Quartus Programmer 載入對應的 `.rbf` 檔案。
    > [!IMPORTANT]
    > * **重要安全機制**：若 FPGA 未載入或 Bridge 未開啟，HPS 存取 `0xFF200000` 位址空間時會導致 **Data Abort (資料終止異常)**，造成系統當機。

3. **偵錯配置**：
   * 在 `Debug Control` 視窗點選 `Connect with an existing Config...` 並選擇 `config_hardware`。
   * **若無法連線 (Unable to connect)**，請手動校對設定：
     * **Connection**: 選擇 `Intel SoC FPGA` -> `Cyclone V SoC (Dual Core)` -> `Bare Metal Debug` -> `Debug Cortex-A9_0`。
     * **Bare Metal Debug**: 確保顯示 `DE-SoC on localhost [USB-1]`。
     * **Files 標籤頁**: 檢查 `Application on host to download` 是否指向 `${workspace_loc:/DE10_serial_parallel/Debug/DE10_serial_parallel.axf}` 並勾選 `Load symbols`。
     * **Debugger 標籤頁**: 在 `Run control` 選擇 `Debug from symbol` 並填入 `main`；同時確保 `Run target initialization debugger script` 已載入 `${workspace_loc:/DE10_serial_parallel/bootloader/preloader.ds}` 以完成 HPS 初始化。
     * **OS Awareness 標籤頁**: 在 `Select OS awareness` 選擇 `Keil CMSIS-RTOS RTX`，以利在偵錯時觀察 **RTOS v2** 任務狀態。

4. **開始偵錯與執行**：
   * 確認上述設定無誤後，點選視窗右下角的 **`Debug`** 按鈕。
   * **下載與掛載**：IDE 將會開始燒錄 `.axf` 執行檔至 HPS 記憶體，並根據設定自動停在 `main` 函式的起始點。

5. **啟動運行**：在 `Debug Control` 視窗點選 `Continue (F8)`，系統才會正式進入 main 並啟動核心調度。

### Step 4: 顯示輸出資訊 (Monitoring)

1. **確認 COM Port 編號**：
   * 在 Windows 任務欄的「開始」圖示點選右鍵，選擇 **「裝置管理員 (Device Manager)」**。
   * 展開 **「連接埠 (COM 和 LPT)」** 項目。
   * 尋找名稱含有 **`Altera USB-Blaster II`** 或 **`USB Serial Port`** 的項目，並記下其後方的編號（例如：`COM3`）。

2. **開啟並配置 PuTTY**：
   * 啟動 **PuTTY** 程式。
   * 在 `Connection type` 選擇 **`Serial`**。
   * 在 `Serial line` 欄位輸入剛才確認的編號（如 `COM3`）。
   * 在 `Speed` 欄位輸入 **`115200`** 。
   * 點選 **`Open`** 開啟終端機視窗。

3. **開始執行與觀測**：
   * 回到 ARM DS 偵錯界面，點選 `Debug Control` 中的 **`Continue (F8)`**。
   * 此時系統正式啟動，你可以在 PuTTY 視窗中即時觀測到 GPS 接收器的初始化資訊、衛星追蹤狀態以及經緯度等運算數據。

## 5. 硬體資源配置 (Hardware Resource Allocation)

本專案透過 **Lightweight HPS-to-FPGA Bridge** 存取 FPGA 端的自定義模組，並透過 **GIC (Generic Interrupt Controller)** 進行即時事件管理。

### 5.1 暫存器映射與基底位址 (Register Map & Base Address)

所有硬體模組均掛載於 HPS 物理位址 `0xFF200000` 開始的空間。

| 模組名稱 | 系統基底位址 (System Base) | 內部偏移量 (Offset) | 說明 |
| --- | --- | --- | --- |
| **Serial Search** | `0xFF200000` | `0x000` | 13 個衛星追蹤通道與系統時序控制。 |
| **Parallel Search** | `0xFF200400` | `0x400` | 平行碼相位搜尋加速模組 (Acquisition)。 |
| **MAX2769** | `0xFF200820` | `0x820` | 射頻前端 SPI 控制暫存器。 |

詳細的定義與暫存器描述請參考：  
👉 [詳細暫存器定義說明書](../../docs/register_map.md)

### 5.2 執行緒清單 (Thread List)

| 線程 (Thread) | 優先度 (Priority) | 功能說明 |
| --- | --- | --- |
| **`measure_thread`** | `osPriorityRealtime` | 負責計算 PVT (Position, Velocity, Time) 解算。 |
| **`message_thread`** | `osPriorityHigh` | 負責導航電文子框 (Subframe #1~#5) 的內容解析。 |
| **`parallel_search_thread`** | `osPriorityAboveNormal` | 觸發 Parallel Search 硬體加速模組並讀取解算結果。  |
| **`allocate_thread`** | `osPriorityAboveNormal` | 分配與初始化 Serial Search 通道參數。 |
| **`display_thread`** | `osPriorityNormal` | 透過 UART0 即時顯示系統狀態與衛星資訊。 |

### 5.3 中斷向量映射 (Interrupt Mapping)

中斷訊號直接連接至 HPS GIC，驅動對應的處理函數與事件轉發。

| 中斷來源 (Interrupt) | GIC ID | 處理函數 (Handler) | 功能說明 |
| --- | --- | --- | --- |
| **FPGA_IRQ0** | 72 | `tracking_IRQ` | 每 0.5ms 由 FPGA 發送，更新各通道追蹤狀態與參數。  |
| **FPGA_IRQ1** | 73 | `parallel_search_IRQ` | Parallel Search 運算完成時觸發，讀取硬體運算結果。 |
| **UART0_IRQ** | 194 | `set_display_command` | 鍵盤敲擊觸發 (RX IRQ)，讀取使用者輸入字元。 |

## 6. 技術實作細節 (Implementation Details)

### 6.1 軟體架構與執行緒 (Software Architecture & Threads)

本專案基於 **CMSIS RTOS v2** 實現多執行緒並行處理，主要執行緒分配如下：

```c
// 核心任務初始化
allocate_thread_id        = osThreadNew(allocate_thread, ...);        // 衛星通道分配與狀態管理
parallel_search_thread_id = osThreadNew(parallel_search_thread, ...); // 平行搜尋模組調度
message_thread_id         = osThreadNew(message_thread, ...);         // 導航電文解析 (50 Hz)
measure_thread_id         = osThreadNew(measure_thread, ...);         // 虛擬距離測量 (10 Hz)
display_thread_id         = osThreadNew(display_thread, ...);         // 終端機資訊輸出
```

### 6.2 平行碼相位搜尋流程 (Parallel Code Phase Search Flow)

為縮短擷取時間，系統採用「混合式搜尋架構」。當 `allocate_thread` 偵測到通道閒置時，會透過 `osThreadFlags` 通知 `parallel_search_thread` 啟動硬體加速器。

* **執行效率對比**：相較於直接搜尋法（需時約 80,725 ms），本專案的平行搜尋演算法僅需 **4.07 ms** 即可完成單顆衛星搜尋，效能提升顯著。
* **同步機制 (Slew Control)**：在取得碼相位（Code Phase）後，韌體會計算理論 Slew 值並調整衛星通道 NCO，確保硬體追蹤通道能精準鎖定訊號。

| 訊號擷取演算法 | 衛星數量 | 搜尋範圍 | 執行時間 | 效能提升 |
| --- | --- | --- | --- | --- |
| **Serial Search** | 1 顆 | $\pm 10$ kHz | ~80,725 ms | 基準 |
| **Parallel Code Phase Search** | 1 顆 | $\pm 10$ kHz | **4.07 ms** | **~19,800x** |

### 6.3 數據流與狀態轉移 (Data Flow & FSM)

本專案優化了衛星通道的狀態機轉移邏輯，將原本序列搜尋（Serial Search）所需的擷取與確認階段，簡化為由硬體加速器引導的 `Refine` 階段。

#### 6.3.1 狀態機比較圖 (State Machine Comparison)
``` mermaid
stateDiagram-v2
    direction LR

    state "原始架構 (Serial Search Only)" as original {
        direction LR
        OFF_orig: OFF
        Acquire: Acquire (1ms/20ms)
        Confirm: Confirm
        PullIn_orig: Pull-in
        Lock_orig: Lock

        OFF_orig --> Acquire
        Acquire --> Confirm
        Confirm --> PullIn_orig
        PullIn_orig --> Lock_orig
        
        Confirm --> OFF_orig: Fail
        PullIn_orig --> OFF_orig: Lost
    }

    state "混合架構 (Serial + Parallel Search)" as hybrid {
        direction LR
        OFF_hyb: OFF
        Refine: Refine (Hardware Guided)
        PullIn_hyb: Pull-in
        Lock_hyb: Lock

        OFF_hyb --> Refine: Parallel Search Done
        Refine --> PullIn_hyb
        PullIn_hyb --> Lock_hyb
        
        Refine --> OFF_hyb: Fail
        PullIn_hyb --> OFF_hyb: Lost
    }
```

#### 6.3.2 邏輯說明

* **原始架構**：必須經歷 `Acquire`（擷取）與 `Confirm`（確認）階段，這在 Serial Search中是透過不斷位移碼相位與載波頻率來實現的，也是最耗時的部分。
* **混合架構 (本專案)**：新增了 **`Refine`** 狀態。 由於 **Parallel Code Phase Search** 模組已經提供了精確的初始相位與頻率偏移，韌體僅需在 `Refine` 階段進行最後的窄頻對齊，即可直接跳轉至 `Pull-in` 鎖定，取代了訊號擷取耗時的搜尋流程。

### 6.4 訊號擷取模式配置 (Acquisition Mode Configuration)

本專案之基頻硬體搜尋策略支援在編譯時期（Compile-time）進行靜態配置。透過修改硬體描述層的巨集定義，即可自由切換 `Serial Search` 或是 `Hybrid (Parallel Code Phase Search + Serial Search)`。

* **檔案位置**：`firmware/hps_core/DE10_serial_parallel/INC/namuru.h`
* **巨集定義切換**：透過註解控制以下巨集定義即可完成切換：

    ```c
    // Hybrid mode (Parallel Code Phase Search + Serial Search)
    #define ACQ_MODE_SYSTEM ACQ_MODE_HYBRID

    // Only Serial Search
    // #define ACQ_MODE_SYSTEM ACQ_MODE_SERIAL
    ```

## 7. 已知問題與解決方案 (Known Issues)
* **Linker Warning L6329W**: 
  - 現象：`Pattern *(correlation_section) only matches removed unused sections.` / `Pattern *(data_CDC_section) only matches removed unused sections.`
  - 原因：Scatter file 預留了資料交換區塊，但目前的實作尚未宣告對應變數。
  - 影響：不影響功能，可忽略或在 .sct 檔中註解。

* **GPS 週數翻轉物理限制 (GPS Week Rollover Handling)**:
  - **位置**：`ephemeris.c` 中的 `process_subframe1()` 函式。
  - **現象**：GPS 導航電文第一子框架（Subframe 1）中的週數（Week Number）欄位僅有 10 bits，其物理上限為 $2^{10} = 1024$ 週（約 19.7 年），期滿即觸發 Rollover 清零。目前底層舊有常式採用硬編碼（Hard-coded）直接加 1024 週的方式來盲猜當前世紀時間。
  - **影響與修正建議**：此機制會導致全系統在面臨 **Rollover #2（2019/04/06）** 之後的現代真實時間場景時產生解算誤差（例如將目前時間誤判為 2000 ~ 2019 年之間）。若需將本系統部署於真實空域或最新模擬器場景中進行長時間量測，**請務必修改該處常式，根據當前真實年份將模數偏置（Offset）調整為 2048 週**，以利後端 PVT 矩陣導出正確的 UTC 時間戳記。

## 專案參考 (References)

### 硬體與底層技術手冊

* **[Intel Cyclone V HPS Address Map](https://www.intel.com/content/www/us/en/programmable/hps/cyclone-v/hps.html)**: 詳列 HPS 暫存器定義、中斷 ID 以及 **Lightweight HPS-to-FPGA Bridge** 的物理位址映射。
* **[Terasic DE10-Nano User Manual](https://www.terasic.com.tw/cgi-bin/page/archive.pl?Language=English&No=1046&PartNo=4)**: 提供開發板電路架構、USB-Blaster II 介面及周邊 Pinout 說明。
* **[CMSIS RTOS v2 Documentation](https://arm-software.github.io/CMSIS_5/RTOS2/html/index.html)**: 關於 `osThreadNew`、`osThreadFlags` 等 API 使用規範之官方文件。

### 開源框架與學術文獻

* **[Namuru V2 GNSS Project Reference](https://unsworks.unsw.edu.au/bitstreams/432f137e-324f-4682-beb5-ab08175aabf0/download)**: 本專案之軟體框架（如任務優先權、數據流結構）高度參考此開源專案。該報告由新南威爾斯大學 (UNSW) 發表，提供 12 Channel Correlator 與導航電文解析之核心邏輯。

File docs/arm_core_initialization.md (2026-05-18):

# Cyclone V HPS 底層暫存器與時脈校正指南

本文件紀錄了本專案在 ARM DS 或 DS-5 環境下，為了正確驅動 CMSIS RTOS v2 (Keil RTX5) 與 HPS 底層周邊，針對 ARMCA9 核心配置進行關鍵的底層修正。

> [!NOTE]
> 本專案已將所有修正完畢的標頭檔與設定直接納入版本控制。當您匯入專案時，正確的硬體參數與暫存器位址會自動覆蓋 (Override) 系統預設值，一般情況下您無需手動修改任何程式碼。本文件僅供環境核對與底層時脈/硬體原理解析使用。

## 目錄
- [Cyclone V HPS 底層暫存器與時脈校正指南](#cyclone-v-hps-底層暫存器與時脈校正指南)
  - [目錄](#目錄)
  - [核心修正與架構核對清單](#核心修正與架構核對清單)
    - [1. GIC 與 Private Timer 實體硬體位址修正](#1-gic-與-private-timer-實體硬體位址修正)
    - [2. 主頻時脈校正與 Private Timer 分頻計算](#2-主頻時脈校正與-private-timer-分頻計算)
    - [3. 關閉虛擬記憶體管理單元 (Disable MMU)](#3-關閉虛擬記憶體管理單元-disable-mmu)
    - [4. 記憶體基底重映射 (Memory Base Remapping)](#4-記憶體基底重映射-memory-base-remapping)
    - [5. 編譯優化等級配置說明 (Optimization Level)](#5-編譯優化等級配置說明-optimization-level)
    - [6. 記憶體佈局與核心區段配置 (Scatter File Configuration)](#6-記憶體佈局與核心區段配置-scatter-file-configuration)
    - [7. RTOS 核心內核配置與執行緒上限核對 (RTX Kernel Configuration)](#7-rtos-核心內核配置與執行緒上限核對-rtx-kernel-configuration)
  - [專案參考 (Reference)](#專案參考-reference)

## 核心修正與架構核對清單

### 1. GIC 與 Private Timer 實體硬體位址修正

  * **檢視檔案**：專案目錄下的 `INC/ARMCA9.h`
  * **修正原理**：標準 Cortex-A9 的 GIC 分配器與 Private Timer 預設位址（`0x2C00_XXXX`）與 Cyclone V HPS 的實體暫存器映射地圖不符。本專案已在本地標頭檔中將其強制重對映至 Intel 官方規範之 `0xFFFE_XXXX` 位址，確保 FPGA 中斷訊號與系統計時器能被正確捕捉。

  * **正確配置核對 (After)**：

      ```c
      #define GIC_DISTRIBUTOR_BASE (0xFFFED000UL)
      #define GIC_INTERFACE_BASE   (0xFFFEC100UL)
      #define GLOBAL_TIMER_BASE    (0xFFFEC200UL)
      #define TIMER_BASE           (0xFFFEC600UL)
      ```

### 2. 主頻時脈校正與 Private Timer 分頻計算

  * **檢視檔案**：專案目錄下的 `RTE/Device/ARMCA9/system_ARMCA9.c`
  * **修正原理**：
    1. **MPU 實際主頻**：雖然 Intel Quartus Platform Designer (Qsys) 中 MPU 時脈預設標註為 800 MHz，但當 DE10-Nano 開機並執行 Preloader 時，硬體會將 MPU 主頻（`mpu_base_clk`）重新配置為 **925 MHz**，系統時脈計算須以 Preloader 實際運行之數值為主。
    2. **OS Tick 來源分頻**：CMSIS RTOS v2 的系統時鐘（OS Tick）完全依賴 Cortex-A9 內部的 Private Timer。根據 Intel 官方發佈之 *Cyclone V Hard Processor System Technical Reference Manual* 規範，Private Timer 的時鐘來源為 `mpu_periph_clk`，其頻率為 MPU 主頻固定 **4 分頻**（925 MHz / 4 = 231.25 MHz）。因此，必須將 `SYSTEM_CLOCK` 常數精確修正為 `231250000U`，否則系統任務排程與 `osDelay` 時間將嚴重失準。

  * **正確配置核對 (After)**：
     ```c
     #define  SYSTEM_CLOCK  231250000U
     ```

### 3. 關閉虛擬記憶體管理單元 (Disable MMU)

  * **檢視檔案**：專案目錄下的 `RTE/Device/ARMCA9/system_ARMCA9.c` (內部的 `SystemInit` 函數)
  * **修正原理**：在即時作業系統（RTOS）與 HPS 硬體混合架構下，為了讓 CPU 核心直接透過實體位址存取 FPGA 側的記憶體對映 (Memory-mapped) 暫存器（`0xFF200000`）與核心周邊，專案中已將預設開啟的 MMU 轉譯功能改為停用。

  * **正確配置核對 (After)**：
      ```c
      // Create Translation Table
      // MMU_CreateTranslationTable();

      // Enable MMU
      // MMU_Enable();
      ```

### 4. 記憶體基底重映射 (Memory Base Remapping)

  * **檢視檔案**：專案目錄下的 `RTE/Device/ARMCA9/mem_ARMCA9.h`
  * **修正原理**：預設位址 `0x80000000` 位於外部 SDRAM。但在除錯引導階段，為了確保 RTOS 核心能直接在 HPS 內部的 On-Chip RAM 穩定執行，本專案已將暫存空間修正至 `0x00000000` 實體起始位址，避免在未初始化外部 SDRAM 前發生存取錯誤。

  * **正確配置核對 (After)**：
      ```c
      #define __ROM_BASE       0x00000000
      #define __RAM_BASE       0x00200000
      #define __TTB_BASE       0x10000000

      #define __RW_DATA_SIZE   0x00100000
      ```

### 5. 編譯優化等級配置說明 (Optimization Level)
  
  * **專案預設配置**：本專案的編譯優化等級**已預先在專案設定檔中鎖定為 `-O0`**。當您匯入專案至 ARM DS 或 DS-5 後，系統會自動套用此配置，一般情況下無需手動修改。
  * **設定核對路徑**：若需確認配置，可於專案點選右鍵 -> `Properties` -> `C/C++ Build` -> `Settings` -> `Tool Settings` -> `ARM C/C++ Compiler` -> `Optimization`，確認等級為 **`-O0` (Minimum optimization / Do not optimize)**。
  * **修正原理**：鎖定 **`-O0`** 可防止編譯器因高階優化進行指令重排、將核心狀態鎖死於 CPU 暫存器、省略硬體指標讀寫，或破壞 Cortex-A9 的 8-Byte 堆疊對齊，從而確保 RTOS 任務切換與底層暫存器控制的時序完全精準。

### 6. 記憶體佈局與核心區段配置 (Scatter File Configuration)

  * **檢視檔案**：專案目錄下的 `RTE/Device/ARMCA9/ARMCA9_ac6.sct`
  * **修正原理**：
    1. **SDRAM 範圍修正**：本專案已將預設的分散載入空間調整為 `0x00000000 0x40000000`（實體 1 GB 空間），以完全符合 Cyclone V HPS 實體記憶體地圖的定址規範。
    2. **自定義專屬硬體快取區段**：為了優化衛星訊號處理之並行運算效率，並確保跨時鐘域（CDC）數據流傳輸的穩定性，本專案在 Scatter file 中顯式定義了兩個獨立的核心數據區段。編編譯器會自動將其配置於高速實體記憶體特定位址中，避免與系統常規變數或執行緒堆疊（Stack）產生資源衝突。
  * **正確配置核對 (After)**：

      ```c
      /* 衛星訊號運算專屬儲存區域 */
      CORRELATION_REGION 0x00600000 CORRELATION_SIZE
      { *(correlation_section) }                                 
      
      /* 跨時鐘域處理數據流專屬儲存區域 */
      DATA_CDC_REGION 0x02000000 DATA_CDC_SIZE
      { *(data_CDC_section) }
      ```

  * **相關連結器警告說明 (Linker Warning L6329W)**：

    * **警告訊息**:當編譯專案時，`主控台 (Console)` 可能會輸出以下警告訊息：
        ```text
        "ARMCA9_ac6.sct", line 86: Warning: L6329W: Pattern *(correlation_section) only matches removed unused sections.
        "ARMCA9_ac6.sct", line 89: Warning: L6329W: Pattern *(data_CDC_section) only matches removed unused sections.
        ```

    * **原因解析**：此警告代表 ARM Linker 在連結階段時，發現 C 原始碼中**目前尚未有變數或函式實際使用 `__attribute__((section("correlation_section")))` 進行宣告**，或是該宣告的變數因未被程式碼呼叫而被優化器判定為無效區段。
    * **處理對策**：此為正常現象，並不影響系統編譯與其餘功能的運行。當後續演算法開發完成並正確指定對應區段後，此警告將自動消失；或可視需求在代碼中使用 `__attribute__((used))` 強制保留該區段。

### 7. RTOS 核心內核配置與執行緒上限核對 (RTX Kernel Configuration)

* **檢視檔案**：專案目錄下的 `RTE/CMSIS/RTX_Config.h`
* **修正原理**：在 CMSIS RTOS v2 (Keil RTX5) 內核中，系統心跳（OS Tick）預設已配置為 **1000 Hz**（即每 1 ms 觸發一次系統排程），核心時脈則會自動咬合並同步繼承自 `system_ARMCA9.c` 中修正完畢的 `SYSTEM_CLOCK` 常數。然而，為了配合本專案包含衛星訊號並行搜尋、追蹤、PVT 運算以及顯示等多任務並行的複雜架構，必須手動放寬內核允許的最大執行緒數量上限，避免 RTOS 核心在初始化階段因資源超限而拒絕建立新執行緒。

* **關鍵配置核對 (After)：**

    ```c
    // 限制系統同時執行的最大執行緒數量 (包含使用者執行緒與內核常駐執行緒)
    #define OS_THREAD_NUM             8
    ```

## 專案參考 (Reference)

* **[Intel Cyclone V HPS Address Map](https://www.intel.com/content/www/us/en/programmable/hps/cyclone-v/hps.html)**: 詳列 HPS 暫存器定義、中斷 ID 以及 Lightweight HPS-to-FPGA Bridge 的物理位址映射。
* **[Cyclone® V Hard Processor System Technical Reference Manual](https://www.intel.com/programmable/technical-pdfs/683126.pdf)**: 官方技術手冊，主要參考第 2 章的 Clock Manager 與 Private Timer 時脈分頻架構。
* **[CSDN 參考文獻：Cortex-A9 RTOS 移植異常分析與解決對策](https://blog.csdn.net/qq_28576837/article/details/124969857)**: 關於通用 CMSIS 軟體包在 Cortex-A9 實體硬體上重對映的底層邏輯參考。

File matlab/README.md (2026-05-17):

# GPS Acquisition - Parallel Code Phase Search Simulation

本專案基於 **MATLAB** 開發，實現了 GPS 訊號擷取階段的 **平行碼相位搜尋演算法 (Parallel Code Phase Search)**。本程式作為演算法的**驗證標準**，目的是確保演算法邏輯正確，以利後續在 SoC 平台上進行軟硬體電路的實作與比對。

## 開發環境與軟體需求

* **開發軟體**：MATLAB R2025b (或相容版本)
* **所需工具箱 (Toolboxes)**：
    * Signal Processing Toolbox
    * Communications Toolbox

## 演算法核心與功能

本模擬腳本（`parallel_code_phase_search_sim.m`）完整涵蓋了從前端基頻訊號模擬到頻域平行搜尋的完整鏈路：

1.  **訊號模擬前端**：生成包含多普勒頻移（Doppler Shift）、C/A 碼相位偏移（Code Phase Offset）以及導航數據（Navigation Data）的 GPS 基頻訊號。
2.  **下採樣與降頻 (Downsampling)**：針對硬體實現進行優化，模擬基頻降頻與移動平均（Moving Sum）處理。
3.  **平行碼相位搜尋演算法**：利用快速傅立葉變換（FFT/IFFT）在頻域對 1 至 32 顆衛星的 C/A 碼進行二維平行搜尋，大幅加速訊號擷取（Acquisition）時間。
4.  **結果驗證與 3D 視覺化**：繪製二維搜尋空間的相關能量圖（Correlation Map），自動追蹤並標記最大峰值（Peak），以驗證演算法在存在導航數據反轉時的擷取可行性。

## 如何執行

1.  將本儲存庫複製（Clone）或下載至本地端。
2.  開啟 **MATLAB** 軟體，並將工作目錄切換至本資料夾。
3.  在 MATLAB 的 Command Window 中輸入並執行以下指令：
    ```matlab
    parallel_code_phase_search_sim
    ```
4.  執行完成後，MATLAB 將自動彈出兩張驗證圖表：
    * **Figure 1**：3D 全衛星平行碼搜尋空間能量分佈圖（自動標記最強 Peak 衛星）。
    * **Figure 2**：模擬的導航數據時域圖，以及最強衛星在最大多普勒頻帶下的相關值切片（Correlation Slice）。

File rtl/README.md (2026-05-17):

# GPSR - FPGA Verilog Implementation
本專案實作於 Intel Cyclone V SoC (DE10-Nano) 平台，實現 GPS 接收機架構，包含硬體 (Verilog) 與軟體 (Firmware) 的協作設計。

## 目錄
- [GPSR - FPGA Verilog Implementation](#gpsr---fpga-verilog-implementation)
  - [目錄](#目錄)
  - [1. 開發環境 (Prerequisites)](#1-開發環境-prerequisites)
    - [軟體工具 (Software Tools)](#軟體工具-software-tools)
    - [硬體平台 (Hardware Platform)](#硬體平台-hardware-platform)
  - [2. Quartus 專案配置](#2-quartus-專案配置)
    - [核心檔案說明](#核心檔案說明)
  - [3. 如何執行 (Getting Started)](#3-如何執行-getting-started)
    - [3.1. 環境檢查清單 (Pre-flight Check)](#31-環境檢查清單-pre-flight-check)
    - [3.2. 圖形化介面操作 (GUI Flow)](#32-圖形化介面操作-gui-flow)
    - [3.3. 自動化編譯流程 (CLI / Makefile Flow)](#33-自動化編譯流程-cli--makefile-flow)
  - [4. Avalon Bus 暫存器映射 (Register Map)](#4-avalon-bus-暫存器映射-register-map)
  - [5. 重要提醒 (Important Notices)](#5-重要提醒-important-notices)
  - [資源使用量 (Resource Utilization)](#資源使用量-resource-utilization)
  - [參考資料與文獻 (References)](#參考資料與文獻-references)
    - [核心架構參考 (Core Architecture)](#核心架構參考-core-architecture)
    - [開發資源與技術文獻 (Technical Resources)](#開發資源與技術文獻-technical-resources)

## 1. 開發環境 (Prerequisites)

### 軟體工具 (Software Tools)

* **Quartus Prime**: Version 25.1std.0 (Lite Edition)
* **SoC FPGA Embedded Development Suite**: Version 20.1 (Standard Edition)
* **Platform Designer**: (前身為 Qsys) 用於構建 Avalon Bus 系統

### 硬體平台 (Hardware Platform)

* **Terasic DE10-Nano Development Kit**:
  * **FPGA**: Cyclone V SE 5CSEBA6U23I7
  * **HPS**: Dual-core ARM Cortex-A9

## 2. Quartus 專案配置
### 核心檔案說明
| 檔案名稱 | 說明 |
| --- | --- |
| `rtl/DE10_NANO_SoC_GHRD.qpf` | Quartus 專案主檔案 (Project File) |
| `rtl/DE10_NANO_SoC_GHRD.qsf` | 專案設置與 Pin Assignment (Setting File) |
| `rtl/DE10_NANO_SoC_GHRD.sdc` | 時序約束檔案 (Synopsys Design Constraints) |
| `rtl/DE10_NANO_SoC_GHRD.v` | Top-level 頂層模組 |
| `rtl/soc_system.qsys` | Platform Designer (HPS-FPGA Bridge) 配置檔 |

## 3. 如何執行 (Getting Started)
在執行任何編譯指令前，請務必確認開發環境已正確配置。

### 3.1. 環境檢查清單 (Pre-flight Check)
> [!NOTE]
> Quartus路徑及EDS路徑需依實際安裝位置自行替換。

請依序確認以下工具是否已加入 Windows **環境變數 (System PATH)**，否則 `make` 指令將無法呼叫編譯器。

1. Quartus 工具鏈
   * **路徑**：`C:\altera_lite\25.1std\quartus\bin64`
   * **驗證**：在終端機輸入 `quartus_sh -v`。
   * **預期結果**：顯示 Quartus Prime 版本資訊。

2. Platform Designer (Qsys)
   * **路徑**：`C:\altera_lite\25.1std\quartus\sopc_builder\bin`
   * **驗證**：在終端機輸入 `qsys-script --help`。
   * **預期結果**：顯示 qsys-script 的參數說明。

3. SoC Embedded Development Suite (EDS)
   * **路徑**：`C:\intelFPGA\20.1\embedded\ip\altera\hps\altera_hps\hwlib\include`
   * **驗證**：`if exist "C:\intelFPGA\20.1\embedded\ip\altera\hps\altera_hps\hwlib\include\soc_cv_av\socal\hps.h" (echo File Found) else (echo File Missing)`。
   * **預期結果**：顯示 File Found

4. Make 編譯工具 (MinGW)
   * **安裝**：若未安裝，請至 [MinGW SourceForge](https://sourceforge.net/projects/mingw/) 下載。
   * **驗證**：在終端機輸入 `make -v`。
   * **預期結果**：顯示 `GNU Make` 版本資訊。

### 3.2. 圖形化介面操作 (GUI Flow)

若需要手動編譯專案，請參考以下步驟：

1. **開啟專案**：
   * 啟動 Quartus Prime
   * 點選 `File` -> `Open Project`，選擇 `rtl/DE10_NANO_SoC_GHRD.qpf`。

2. **配置 FFT/IFFT IP檔案**：
   * **開啟工具**：點選選單 `Tools` -> `Platform Designer`。
   * **開啟專案**：在彈出視窗中選取並載入 `rtl/ip/FFT_IFFT/FFT_IFFT.qsys`。
   * **關鍵參數檢查**：
     * **Length**: `4096`
     * **Direction**: `Bi-directional`
     * **Data Flow**: `Variable Streaming`
     * **Input Order**: `Natural`
     * **Output Order**: `Digit Reverse`
     * **Representation**: `Single Floating Point`
   * **生成硬體 (Generate HDL)**：
     * 確認參數無誤後，請點選右下角 **[Generate HDL...]**。
     * 在彈出的 `Generation` 視窗中：
     * **取消勾選** `Create block symbol file (.bsf)`（可縮短生成時間）。
     * 點選 **[Generate]** 開始轉換硬體描述語言。
   * **結束配置**：
     * 出現 `Generate: completed with warnings` 是正常現象，請直接點選 `Close`。
     * 點選 `Finish` 關閉 Platform Designer，回到 Quartus 主介面。

3. **配置 頂層 Platform Designer (soc_system)**：
   * **開啟工具**：點選選單 `Tools` -> `Platform Designer`。
   * **開啟專案**：載入檔案 `rtl/soc_system.qsys`。
   * **SPI 關鍵參數檢查**：
     * 在 System Contents 視窗中雙擊 **`spi_0`** (或對應的 SPI IP)。
     * **重要設定**：確保 `Clock polarity` 與 `Clock phase` 皆為 **`0`**，且資料寬度為 **`32`** bits，否則將導致 DE10-Nano 無法正確與 MAX2769 發送參數。
   * **生成硬體 (Generate HDL)**：
     * 若為第一次編譯、或是曾修改過 `rtl/verilog/` 下的檔案，請點選右下角 **[Generate HDL...]**。
     * 在彈出的 `Generation` 視窗中：
     * **取消勾選** `Create block symbol file (.bsf)`（可縮短生成時間）。
     * 點選 **[Generate]** 開始轉換硬體描述語言。
   * **結束配置**：
     * 出現 `Generate: completed with warnings` 是正常現象，請直接點選 `Close`。
     * 點選 `Finish` 關閉 Platform Designer，回到 Quartus 主介面。

4. **開始編譯**：
   * 點選選單 `Processing` -> `Start Compilation` (編譯時間約25~30分鐘)。

   > [!IMPORTANT]
   > 由於專案架構複雜，編譯過程中若發生無預警崩潰（Crash），請參閱  
   > 👉 [重要提醒：Analysis & Synthesis 崩潰修復](#fix-crash)

5. **燒錄至開發板**：
   1. **硬體連接**：
      * 使用一條 **Mini USB 線** 連接 DE10-Nano 上的 **USB-Blaster II 埠** (J13) 與開發電腦。
      * 無需外接額外的偵錯器硬體，該連線同時提供 JTAG 偵錯與 UART 通訊功能。
   
   2. **開啟燒錄工具**：點選選單 **`Tools` -> `Programmer**`。
   
   3. **檢查硬體偵測 (Hardware Setup)**：
      * 若 `Hardware Setup...` 顯示 **`No Hardware`**，請點選該按鈕。
      * 將 `Currently Selected hardware` 由 `No Hardware` 切換為 **`DE-SoC [USB-1]`**，隨後點選 `Close`。
   
   4. **自動偵測裝置**：
      * 點選左側 **[Auto Detect]**，於彈出視窗選擇 **`5CSEBA6`** 裝置並點選 `OK`。
      * 若跳出詢問視窗：
        > `The auto-detected device chain does not match the Programmer's device list. Do you want to update the Programmer's device list, overwriting any existing settings?`
        > 請直接點選 **`Yes`** (或 OK) 以更新裝置鏈結。
    
    5. **載入編譯檔案**：
         * 於 `5CSEBA6` 裝置上點選右鍵，選擇 **`Change File`**。
         * 路徑指向：`rtl/output_files/DE10_NANO_SoC_GHRD_time_limited.sof`。

    6. **執行燒錄**：
         * 勾選 **`Program/Configure`** 核取方塊。
         * 點選左側 **[Start]** 開始執行。

    7. **確認結果**：
         * 當右上角 **Progress** 顯示 `100% (Successful)` 並跳出 `OpenCore Plus Status` 視窗時，即代表燒錄成功並開始運行。

   > [!IMPORTANT]
   > **運行時限提醒**：由於使用 OpenCore Plus IP，燒錄後請參考下方說明。  
   > 👉 [運行階段：OpenCore Plus 時效限制](#opencore-plus)

> [!TIP]
> **同步韌體位址**：若你在 Platform Designer 中修改了模組基底位址，編譯完硬體後，請務必執行 `make -C rtl header` 來同步韌體開發所需的 `hps_0.h` 標頭檔。

### 3.3. 自動化編譯流程 (CLI / Makefile Flow)
確認 [3.1. 環境檢查清單](#31-環境檢查清單-pre-flight-check) 中的工具皆可正常執行後，即可開始執行自動化編譯流程。

``` makefile
# Quartus 編譯流程(Mapping, Fitting, Assembly)
make -C rtl

# 燒錄板子
make -C rtl flash

# 生成韌體所需的標頭檔(Header File)
make -C rtl header
```

## 4. Avalon Bus 暫存器映射 (Register Map)
本專案包含三個核心模組，詳細的暫存器偏移量與位元定義請參考：  
👉 [詳細暫存器定義說明書](../docs/register_map.md)

| 模組名稱 | 基底位址 (Base Address) | 說明 |
| --- | --- | --- |
| **Serial Search** | `0x000` | 13 個衛星追蹤通道與系統控制 |
| **Parallel Code Phase Search** | `0x400` | 平行碼相位搜尋加速模組 |
| **MAX2769** | `0x820` | 射頻前端控制模組 |

## 5. 重要提醒 (Important Notices)
<span id="fix-crash"></span>

1. 編譯階段: Analysis & Synthesis 崩潰修復
   * **現象**：Quartus 在編譯約3~5分鐘時突然無預警崩潰（Crash），通常發生於 `Analysis & Synthesis` 階段。
   * **報錯資訊**：`Internal Error: Sub-system: OPT, File: /quartus/synth/opt/opt_carry_pack.cpp, Line: 1686` (或任何涉及 OPT 子系統的內部錯誤)。
   * **解決對策**：
     1. **關閉軟體**：關閉 Quartus Prime 軟體。
     2. **清理數據庫**：從專案目錄中手動刪除 **`db`** 與 **`incremental_db`** 兩個資料夾。
     3. **重新編譯**：重啟 Quartus 並重新執行完整編譯 (點選選單 `Processing` -> `Start Compilation`)。
   * **重要備註**：
     * 刪除這些資料夾僅會移除編譯快取，不會影響你的 `.v` 源碼或 `.qsf` 設置檔。
     * 由於邏輯優化過程具備隨機性，若重新編譯後仍遇到相同錯誤，請重複上述步驟直至通過。

2. 編譯階段：EDA Netlist Writer 錯誤
   * **現象**：編譯進度達到 80%~100% 時，最後一項 `EDA Netlist Writer` 會顯示紅色 **Failed**。
   * **原因**：由於專案使用了 FFT/IFFT 等具備 IP 授權限制的模組，Quartus Lite 版本不支援為此類 IP 產生第三方模擬用的網表(EDA Netlist)。
   * **影響**：**完全不影響** 實際的 `.sof` 檔案產生與硬體燒錄，只要其餘編譯階段（如 Fitter, Assembler）皆成功，即可進行燒錄。
   * **解決對策**：
     * 對策一：掛載正式授權
       1. 點選選單`Tools` -> `License Setup...`。
       2. 在左側樹狀選單點選 `IP Settings` -> `License Setup`。
       3. 在右側 `License file` 輸入 `port@server_ip` （例如 27000@140.113.xxx.xxx）。
     * 對策二：關閉 EDA 網表產生
       1. 點選選單`Assignments` -> `Settings`。
       2. 在左側樹狀選單點選 `EDA Tool Settings` -> `Simulation`。
       3. 將右側 `Tool name`選項改為 `<none>`。
       4. 點選 OK 並重新編譯，該錯誤將不再出現。
   * **重要備註**：
     * 模擬限制：若將`Tool name`選項改為 `QuestaSim`，Quartus 才會生成整個專案的模擬所需檔案。
     * 範圍說明：此模擬檔案僅包含 FPGA 內部的邏輯電路（RTL），**不包含** Platform Designer (Qsys) 的 Avalon Bus 系統架構及 HPS (ARM) 硬體端內容。

<span id="opencore-plus"></span>

3. 燒錄階段：OpenCore Plus 時效限制
   * **現象**：燒錄至板子後，若連續運行約 **1 小時**，GPS 訊號追蹤可能會突然異常或中斷。
   * **原因**：專案內含的 FFT/IFFT IP 屬於 OpenCore Plus 評估版，在沒有正式授權 (Standard/Pro License) 的情況下有運行時限。
   * **解決對策**：
     1. 必須保持 **USB Blaster 傳輸線** 連接板子與電腦，不可拔除。
     2. 若 IP 失效導致追蹤失敗，請重新執行 `make flash` 重新燒錄即可恢復運作。

## 資源使用量 (Resource Utilization)

| Resource Type | Usage | Capacity  | Percentage |
| :--- | :--- | :--- | :--- |
| **Logic utilization (ALMs)** | 23,879 | 41,910 | 57% |
| **Total registers** | 40,703 | - | - |
| **Block memory bits** | 1,676,356 | 5,662,720 | 30% |
| **Total DSP Blocks** | 82 | 112 | 73% |

## 參考資料與文獻 (References)

### 核心架構參考 (Core Architecture)

* **[GitHub - kristianpaul/gnss-sdr-ru](https://github.com/kristianpaul/gnss-sdr-ru/tree/master)**: 本專案 GPS 接收機之數位基頻 (Digital Baseband) 硬體架構主要參考此開源專案。

### 開發資源與技術文獻 (Technical Resources)

<!-- * **DE10-Nano User Manual**: 關於 Cyclone V SoC 硬體配置與 HPS-FPGA Bridge 之技術細節。 -->
* **[DE10-Nano User Manual](https://www.terasic.com.tw/cgi-bin/page/archive.pl?Language=English&CategoryNo=205&No=1046&PartNo=4)**: 關於 Cyclone V SoC 硬體配置與 HPS-FPGA Bridge 之技術細節 (Terasic 官方資源)。
* **[Cyclone V Hard Processor System Technical Reference Manual](https://www.intel.com/programmable/technical-pdfs/683126.pdf)**: 包含 HPS 暫存器定義與位址映射 (Address Map) 的權威文件。

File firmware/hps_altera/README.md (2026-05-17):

# GPSR - Altera Edition (Legacy Support)

> [!IMPORTANT]
> **核心開發與導讀建議**
> 1. **專案定位**：本專案僅提供針對 **DS-5 Altera Edition** 環境的編譯配置與差異說明。
> 2. **程式碼來源**：本目錄不包含實體原始碼，所有核心代碼均需從 `hps_core` 手動同步，**請務必參考主開發版本**：
> 👉 **[前往主要開發版本 (hps_core)](../hps_core/README.md)**

## 目錄
- [GPSR - Altera Edition (Legacy Support)](#gpsr---altera-edition-legacy-support)
  - [目錄](#目錄)
  - [1. 開發環境 (Prerequisites)](#1-開發環境-prerequisites)
    - [1.1 DS-5 環境插件必要配置 (CMSIS-Pack Plug-in)](#11-ds-5-環境插件必要配置-cmsis-pack-plug-in)
    - [1.2 CMSIS 軟體包版本限制 (CMSIS 5.9.0)](#12-cmsis-軟體包版本限制-cmsis-590)
  - [2. 專案架構與配置 (Project Structure)](#2-專案架構與配置-project-structure)
  - [4. 如何執行 (Getting Started)](#4-如何執行-getting-started)
    - [Step 0: 複製檔案](#step-0-複製檔案)
    - [Step 1: 匯入專案 (Import Project)](#step-1-匯入專案-import-project)
    - [Step 2: 編譯專案 (Build Project)](#step-2-編譯專案-build-project)
    - [Step 3: 硬體連線與除錯配置 (Debug Configuration)](#step-3-硬體連線與除錯配置-debug-configuration)
    - [Step 4: 顯示輸出資訊 (Monitoring)](#step-4-顯示輸出資訊-monitoring)
  - [檔案差異](#檔案差異)
  - [已知限制與開發建議](#已知限制與開發建議)
  - [已知問題：Assembler 預定義格式錯誤 (A1020E)](#已知問題assembler-預定義格式錯誤-a1020e)
    - [問題描述](#問題描述)
    - [解決辦法 (手動修正 Makefile)](#解決辦法-手動修正-makefile)

## 1. 開發環境 (Prerequisites)
* **硬體平台**: Terasic DE10-Nano (Cyclone V 5CSEBA6U23I7)。
* **開發環境**: ARM DS-5 Intel SoC FPGA Edition (Version 5.29.1)。
* **開發套件**: SoC FPGA Embedded Development Suite Standard Edition (Version 20.1)。
* **作業系統**: CMSIS RTOS v2。
* **編譯器**: ARM Compiler 5 (AC5)。
* **終端機軟體**: PuTTY (用於透過 UART 觀察系統輸出與 HPS 狀態)。
* **硬體需求**: 需先透過 Quartus 編譯並產生 `.rbf` 檔案載入 FPGA，確保 HPS 可透過 Lightweight HPS-to-FPGA Bridge 存取暫存器。

### 1.1 DS-5 環境插件必要配置 (CMSIS-Pack Plug-in)

若使用 DS-5 進行開發，必須安裝插件以支援 **CMSIS-RTOS2 (Keil RTX5)** 與軟體組件管理。系統預設並不支援 CMSIS-Pack 管理器。為了能正確載入專案中的相關軟體組件，必須手動安裝 Eclipse 插件。

1. **下載**：前往 [GitHub](https://github.com/arm-software/cmsis-pack-eclipse/releases) 下載 `CmsisPackPlugIn-2.4.2.zip` 這是 DS-5 5.29.1 所能支援的最高版本）。
2. **安裝**：
   * 開啟 DS-5，透過 `Help` -> `Install New Software...`。
   * 點擊 **`Add...`**，接著點選 **`Archive...`** 並選取剛下載的 `.zip` 檔案。
   * 勾選所有出現的 **CMSIS Pack** 相關組件，並依提示完成安裝（期間可能需要重啟 IDE）。
3. **驗證**：
* 重啟後，對著專案點擊右鍵應可看到 **`Manage Run-Time Environment`** 選項，且能正常開啟 `.rteconfig` 檔案。

### 1.2 CMSIS 軟體包版本限制 (CMSIS 5.9.0)

在安裝完插件後，由於 **ARM Compiler 5 (AC5)** 的語法限制，本專案必須搭配特定版本的 CMSIS 核心庫方能正確編譯。

* **安裝方式**：
  * 從 [Keil 官網](https://www.keil.arm.com/packs/cmsis-arm/versions/) 下載 `ARM.CMSIS.5.9.0.pack`。
  * 開啟 DS-5 中的 **CMSIS Pack Manager** 視窗（若未看到，請點選 `Window` -> `Show View` -> `CMSIS Pack Manager`）。
  * 點選視窗工具列中的 **`Import...`** 按鈕。
  * 選取下載的 `.pack` 檔案完成安裝。

## 2. 專案架構與配置 (Project Structure)

匯入專案後，請確保 `.rteconfig` 中的組件版本如下：

| 類別 (Category) | 組件名稱 (Component) | 變體 (Variant) | 實測版本 (Version) |
| --- | --- | --- | --- |
| **CMSIS** | **CORE** | - | **1.2.1** | 
| **CMSIS** | **OS Tick (API) -> Private Timer** | - | **1.0.2** |
| **CMSIS** | **RTOS2 (API) -> Keil RTX5** | **Source** | **5.5.4** | 
| **CMSIS-Compiler** | **STDIN/STDOUT (API) -> Custom** | - | **1.1.0** | 
| **Device** | **IRQ Controller (API) -> GIC** | - | **1.0.1** | 
| **Device** | **Startup** | - | **1.0.2** | 

## 4. 如何執行 (Getting Started)

本節說明如何將專案匯入 **DS-5 Altera Edition**、編譯並透過 **USB-Blaster II** 進行硬體偵錯。

### Step 0: 複製檔案
由於本目錄僅含設定檔，開始前須手動執行以下複製動作：

1. 複製 `firmware/hps_core/bootloader/*` 到 `firmware/hps_altera/bootloader`。
2. 複製 `firmware/hps_core/DE10_serial_parallel/SRC/*` 到 `firmware/hps_altera/DE10_serial_parallel/SRC`。
3. 複製 `firmware/hps_core/DE10_serial_parallel/INC/*` 到 `firmware/hps_altera/DE10_serial_parallel/INC`。
4. 複製 `firmware/hps_core/DE10_serial_parallel/main.c` 到 `firmware/hps_altera/DE10_serial_parallel/main.c`。

### Step 1: 匯入專案 (Import Project)

1. 啟動 **Eclipse for DS-5 v5.29.1**。
2. 點選選單 `File` -> `Switch Workspace` -> `firmware/hps_altera`。
3. 點選選單 `File` -> `Import...`。
4. 選擇 `General` -> `Existing Projects into Workspace`，並點選 `Next`。
5. 在 `Select root directory` 中點選 `Browse..`，路徑切換至 `firmware/hps_altera/DE10_serial_parallel` 目錄後點選 `選擇資料夾`。
6. 在 `Projects` 清單中勾選 `DE10_serial_parallel`，最後點選 `Finish`。

### Step 2: 編譯專案 (Build Project)

1. 點選選單 `Project` -> `Build All`。
2. **編譯檢查**：
   * 出現 **Warnings** 通常為編譯器優化建議，尚可接受。
   * 若出現 **Errors** 則代表 `.axf` 執行檔未成功生成，請檢查 Include 路徑或 CMSIS 庫配置。

### Step 3: 硬體連線與除錯配置 (Debug Configuration)

1. **硬體連結**：
   * 使用一條 **Mini USB 線** 連接 DE10-Nano 上的 **USB-Blaster II 埠** (J13) 與開發電腦。
   * 無需外接額外的偵錯器硬體，該連線同時提供 JTAG 偵錯與 UART 通訊功能。

2. **硬體檢查**：
   * **指撥開關 (MSEL)**：請確保DE10-Nano 上的 **MSEL[4:0]** 開關設定為 `01010` (FPP 模式)以允許 HPS 透過 FPGA Manager 配置硬體。
   * **FPGA 載入狀態**：在啟動 DS 偵錯前，請務必透過 Quartus Programmer 載入對應的 `.rbf` 檔案。
    > [!IMPORTANT]
    > * **重要安全機制**：若 FPGA 未載入或 Bridge 未開啟，HPS 存取 `0xFF200000` 位址空間時會導致 **Data Abort (資料終止異常)**，造成系統當機。

3. **偵錯配置**：
   * 在 `Debug Control` 視窗右鍵點選 `Debug Configurations...`。
   * 在左側樹狀選單連點兩次 `DS-5 Debugger`。
     * **Connection 標籤頁**: 選擇 `Altera` -> `Cyclone V SoC (Dual Core)` -> `Bare Metal Debug` -> `Debug Cortex-A9_0`。
     * **Connection 標籤頁**: Target Connection 選擇 `USB Blaster`。
     * **Connection 標籤頁**: Bare Metal Debug 點擊 `Connection` 旁的 `Browse...`，選擇 `DE-SoC on localhost [USB-1]`。
     * **Files 標籤頁**: 檢查 `Application on host to download` 是否指向 `${workspace_loc:/DE10_serial_parallel/Debug/DE10_serial_parallel.axf}` 並勾選 `Load symbols`。
     * **Debugger 標籤頁**: 在 `Run control` 選擇 `Debug from symbol` 並填入 `main`；同時確保 `Run target initialization debugger script` 已載入 `${workspace_loc:/DE10_serial_parallel/bootloader/preloader.ds}` 以完成 HPS 初始化。
     * **OS Awareness 標籤頁**: 在 `Select OS awareness` 選擇 `Keil CMSIS-RTOS RTX`，以利在偵錯時觀察 **RTOS v2** 任務狀態。

4. **開始偵錯與執行**：
   * 確認上述設定無誤後，點選視窗右下角的 **`Debug`** 按鈕。
   * **下載與掛載**：IDE 將會開始燒錄 `.axf` 執行檔至 HPS 記憶體，並根據設定自動停在 `main` 函式的起始點。

5. **啟動運行**：在 `Debug Control` 視窗點選 `Continue (F8)`，系統才會正式進入 main 並啟動核心調度。

### Step 4: 顯示輸出資訊 (Monitoring)

1. **確認 COM Port 編號**：
   * 在 Windows 任務欄的「開始」圖示點選右鍵，選擇 **「裝置管理員 (Device Manager)」**。
   * 展開 **「連接埠 (COM 和 LPT)」** 項目。
   * 尋找名稱含有 **`Altera USB-Blaster II`** 或 **`USB Serial Port`** 的項目，並記下其後方的編號（例如：`COM3`）。

2. **開啟並配置 PuTTY**：
   * 啟動 **PuTTY** 程式。
   * 在 `Connection type` 選擇 **`Serial`**。
   * 在 `Serial line` 欄位輸入剛才確認的編號（如 `COM3`）。
   * 在 `Speed` 欄位輸入 **`115200`** 。
   * 點選 **`Open`** 開啟終端機視窗。

3. **開始執行與觀測**：
   * 回到 ARM DS 偵錯界面，點選 `Debug Control` 中的 **`Continue (F8)`**。
   * 此時系統正式啟動，你可以在 PuTTY 視窗中即時觀測到 GPS 接收器的初始化資訊、衛星追蹤狀態以及經緯度等運算數據。

## 檔案差異
| 功能項目 | 主要版本 (hps_core) | Altera 版本 (hps_altera) |
| --- | --- | --- |
| **開發工具** | Arm Development Studio | **DS-5 Altera Edition** |
| **編譯器** | ARM Compiler 6 (LLVM)  | **ARM Compiler 5 (armcc)** |
| **RTOS** | CMSIS RTOS2 (Modern) | CMSIS RTOS2 (Keil RTX5 v5.5.4) |

## 已知限制與開發建議
* **檔案結構說明**：本目錄僅保留 `.project`、`.cproject` 等 IDE 必要設定檔。若未執行 **Step 0**，專案將無法編譯。
* **手動程式碼更新**：本專案**不支援**與 `firmware/hps_core/` 的自動同步。若主專案演算法有更新，須手動將程式碼複製至 `firmware/hps_altera/` 對應目錄。
* **Makefile 狀態控制**：DS-5 預設會自動生成 Makefile，但為了修正 A1020E 錯誤，**本專案要求手動禁用自動構建**。請完全依賴 DS-5 IDE 的編譯管理系統進行手動觸發。
* **編譯優化限制**：**Optimization 等級必須設定為 `-O0`**。
  * 若選擇 `-O1` 以上的優化等級，將導致 **CMSIS-RTOS v2 (RTX5)** 無法正常運作。
  * 點選選單 `Project` -> `Properties`。
  * 在左側樹狀選單點選 `C/C++ Build` -> `Settings`。
  * 在 `Tool Settings` 標籤頁 -> `Arm C Compiler 5` -> `Optimization` -> `Optimization level` : `Minimum (-O0)`。

> [!IMPORTANT]
> **重要：編譯清單重整機制**
> 當專案的**檔案結構有任何增減**時，必須重新啟動自動生成機制，否則新檔案不會被編譯：
> 1. **觸發情境**：
>     * 在 `.rteconfig` 中新增或刪除組件。
>     * 手動在專案中**新增或移除任何 `.c`、`.s` 原始碼檔案**。
> 
> 2. **操作流程**：
>     * 重新勾選 `Generate Makefiles automatically`。
>     * 執行 `Build Project` 讓 IDE 更新編譯清單（此時會再次出現 `A1020E` 錯誤）。
>     * **再次取消勾選**並手動修正 `subdir.mk` 中的參數。

---

## 已知問題：Assembler 預定義格式錯誤 (A1020E)

### 問題描述

在編譯過程中，若組譯器（armasm）處理 `irq_armv7a.S` CMSIS 核心檔案時報錯：

```text
A1020E: Bad predefine: _RTE_
A1020E: Bad predefine: ARMCA9
make: [RTE/CMSIS/subdir.mk:76: RTE/CMSIS/irq_armv7a.o] Error 1
```

這是因為 **CMSIS-Pack Plug-in** 在舊版 **DS-5 (AC5)** 環境中生成的預處理參數格式 `--pd "_RTE_"` 無法被組譯器識別。

### 解決辦法 (手動修正 Makefile)

由於 DS-5 在 AC5 環境下生成的組譯參數格式錯誤，請依以下步驟手動「禁用」並「修正」：

1. **初步編譯**：先執行 `Build Project` 讓 IDE 生成編譯目錄。
2. **禁用自動構建 (關鍵步驟)**：
* 在專案上點擊右鍵 -> `Properties`。
* 導航至 `C/C++ Build` -> 標籤頁 `Builder Settings`。
* **取消勾選** `Generate Makefiles automatically`（防止 IDE 覆蓋您的手動修改）。

3. **修正參數**：
* 開啟檔案：`Debug/RTE/CMSIS/subdir.mk`。
* 將 L76 附近的 `armasm --pd "_RTE_" --pd "ARMCA9"` 指令中，刪除 `--pd "_RTE_" --pd "ARMCA9"`。

4. **重新編譯**：儲存後再次點擊 `Build Project`。

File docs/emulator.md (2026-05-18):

# GPS 訊號模擬器操作指南 (GPS Emulator Guide)

本文件說明實驗室內兩台 GPS 訊號模擬器的基本規格與操作流程，用於驗證 GPS 接收器之追蹤與定位功能。

## GPS 訊號模擬器 (GNSS Emulators)

| 設備名稱 | 型號 | 支援頻段與功能 |
| --- | --- | --- |
| **Agilent ESG** | E4438C  | 支援 GPS L1 靜態/預錄場景播放。 |
| **Spirent Simulator** | GSS7000 | 支援多系統 (GPS/GLONASS) 與多頻段 (L1/L5, G1/G2) 動態軌跡模擬。 |

## 目錄
- [GPS 訊號模擬器操作指南 (GPS Emulator Guide)](#gps-訊號模擬器操作指南-gps-emulator-guide)
  - [GPS 訊號模擬器 (GNSS Emulators)](#gps-訊號模擬器-gnss-emulators)
  - [目錄](#目錄)
  - [設備一：Agilent E4438C ESG Vector Signal Generator](#設備一agilent-e4438c-esg-vector-signal-generator)
    - [功能說明](#功能說明)
    - [操作流程](#操作流程)
  - [設備二：Spirent GSS7000 Signal Generator](#設備二spirent-gss7000-signal-generator)
    - [操作流程](#操作流程-1)
  - [設備狀態與維護紀錄](#設備狀態與維護紀錄)
    - [設備：Agilent E4438C ESG Vector Signal Generator](#設備agilent-e4438c-esg-vector-signal-generator)

## 設備一：Agilent E4438C ESG Vector Signal Generator
本設備主要用於播放預錄的 GPS L1 訊號。

<div align="center">
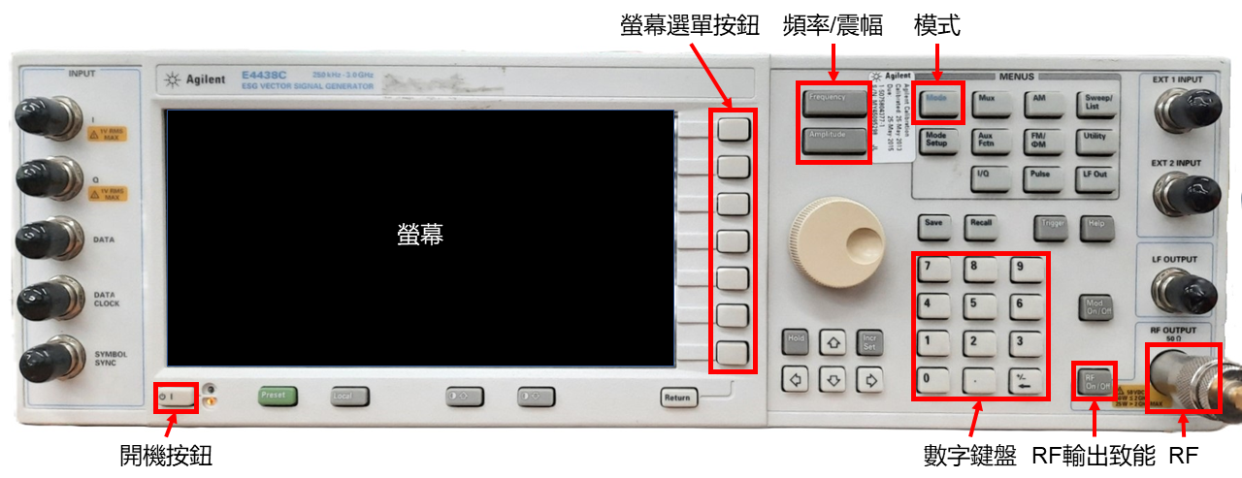
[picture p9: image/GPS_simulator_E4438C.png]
Agilent_E4438C
  
  <p style="margin-top: 10px;"><i>圖：Agilent E4438C ESG Vector Signal Generator</i></p>
</div>

### 功能說明

* **[開機按鈕]**：位於機器面板左下角 。
* **[數字鍵盤]**：位於面板右側，用於輸入頻率與震幅數值 。
* **[RF On/Off]**：位於右下角，這是輸出訊號的最後一道開關 。

### 操作流程
1. 核心參數設定 (Parameters)

   * **頻率 (Frequency)**: `1575.42 MHz` (GPS L1)。

2. 開機與基礎設定
   1. **開機**：按下左下角 [電源按鈕]。
   2. **設定頻率**：按壓面板上的 **[Frequency]** 按鍵，輸入 `1575.42` 並選擇螢幕選單中的 `MHz`。
   3. **設定震幅**：按壓面板上的 **[Amplitude]** 按鍵，輸入 `-110` 並選擇 `dBm`。

3. 進入 GPS 模式
   1. 按壓面板上的 **[Mode]** 按鍵。
   2. 在螢幕右側選單按下 **[More]** (1 of 3) 切換至第二頁。
   3. 選擇 **[GPS]** 進入選單。
   4. 按下 **[Real Time MSGPS]** (Multiple Satellite GPS)。
        > *註：MSGPS 可同時模擬多顆衛星；Real Time GPS 僅能模擬單一衛星。*

4. 選擇場景 (Scenario) 與播放
   1. 按下 **[Scenario]** 進入檔案清單。
   2. 使用轉盤選擇場景，例如 **[HAWAII]** 或 **[SANTAROSA]**，按下 **[Select Scenario]**。
   3. 回到主頁面，按下右側選單最上方的 **[Real-time MSGPS]** 將狀態切換為 **[On]**。
      * 此時螢幕應顯示該場景之經緯度資訊與目前在空衛星編號（Satellites in View）。
      * **注意**：此時基頻訊號已開始播放，但 RF 實體線路尚未輸出。

5. 致能 RF 輸出
   1. 按下面板右下角的 **[RF On/Off]** 按鍵。
   2. 確認螢幕上方狀態欄顯示 **[RF ON]**。
   3. 此時訊號正式從 RF 輸出孔送出至接收器。

---

## 設備二：Spirent GSS7000 Signal Generator

本設備為高階多頻段訊號模擬器，支援 GPS (L1/L5) 與 GLONASS (G1/G2) 等多系統同時模擬。

<div align="center">
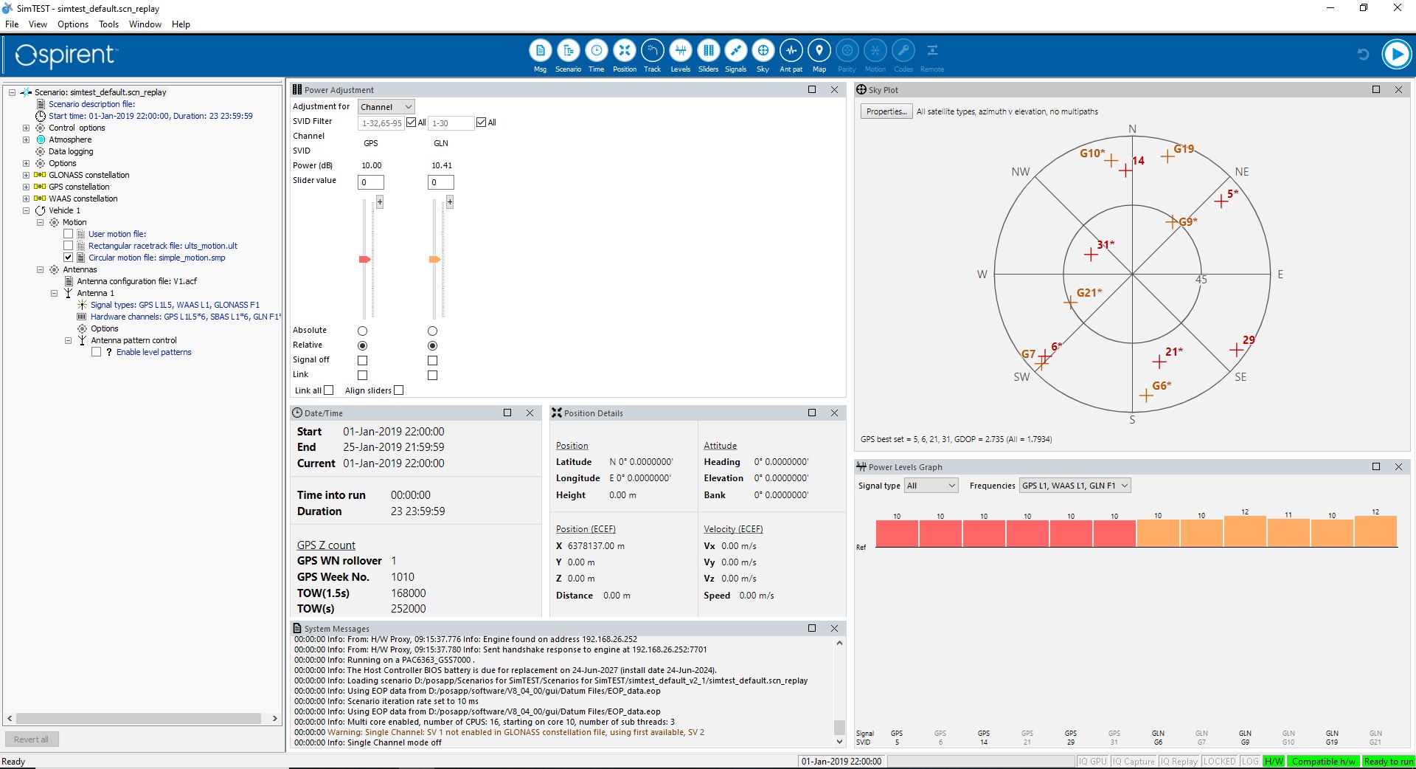
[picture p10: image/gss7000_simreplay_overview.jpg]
gss7000_simreplay_overview
  
  <p style="margin-top: 10px;"><i>圖：Spirent GSS7000 Signal Generator</i></p>
</div>

### 操作流程
1. 硬體與軟體啟動

   * **硬體電源**：開啟 **GSS7000** 主機電源。
   * **系統登入**：輸入 Windows 登入密碼（密碼請參閱實驗室之 **廠商附贈之操作說明(紙張為A4大小)**）。
   * **應用程式**：開啟桌面上的 `Positioning Application`。

2. 載入場景 (Scenario)

   * **檔案路徑**：`D:/posapp/Scenarios for SimTEST/Scenarios for SimTEST/simtest_default_v2_1/simtest_default.scn_replay`。
   * **備份機制**：若場景檔異常，請從 `D:/posapp/back up/Scenarios for SimTEST.zip` 解壓縮並覆蓋回原路徑。

3. 進階參數設定 (僅限播放前)

   * **接收機位置 (Position)**：點選 `simple_motion.smp` 檔案可設定初始經緯度與路徑。
   * **衛星種類 (Signal type)**：調整欲模擬的系統（如 GPS、GLONASS）。
   * **衛星數量 (Hardware Channel)**：設定各個頻段分配的衛星通道數。
   * **功率調整 (Power Level)**：
   * **重要限制**：**僅在 `Ready to run` 階段才能調整訊號強度**。一旦進入播放流程，數值將無法更動。

   * **單頻道模式 (Single Channel Mode)**：
     * 進入路徑：`File` > `Single Channel Mode`。
     * **SVID/PRN 切換**：僅在此模式下的 `Initial State` 分頁中，可以手動指定特定的衛星編號 (SVID) 或 PRN。

4. 播放流程與狀態監測

   * **開始播放**：點擊工具列的 **[Play]** 圖示。
   * **狀態觀察**：請盯住視窗右下角的狀態列，確保其依序完成以下轉變：
   `Ready to run` $\rightarrow$ `Arming` $\rightarrow$ `Trigger wait` $\rightarrow$ **`Running`**。
   * **正式輸出**：必須等到狀態顯示為 **`Running`**，硬體才會正式輸出 RF 訊號。

 5. 結束與恢復

      * **停止播放**：點選 **`[Stop]`** 按鈕，系統停止撥放場景。
      * **解除鎖定**：點選 **`[Revert]`** 按鈕，系統才會釋放播放時的參數鎖定並恢復至場景初始值。

## 設備狀態與維護紀錄

### 設備：Agilent E4438C ESG Vector Signal Generator
* **現況說明**：本設備為二手老舊儀器（近期測試日期：2023年06月19日）。
* **故障排查（Troubleshooting）**：若在硬體連接完全正確的前提下，GPS 接收器（Receiver）仍無法順利解算定位（Position Fix），在排除硬體接線與韌體設定後，應優先懷疑訊號產生器之 RF 輸出異常。
* **原廠/第三方檢修資訊**：
  * 檢修廠商：全測儀器科技股份有限公司 (AllTestek)
  * 官方網站：[全測儀器科技](https://www.alltestek.com/)

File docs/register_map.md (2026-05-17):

# Avalon Bus 暫存器映射 (Register Map)
> [!IMPORTANT]
> **自動化同步**：本文件定義與硬體 RTL 同步。  
> 若修改 Qsys 配置，請在資料夾 `rtl` 中執行 `make header` 以更新 `hps_0.h`，並將檔案複製並蓋寫至`firmware/hps_core/DE10_serial_parallel/INC/hps_0.h`。

## 目錄
- [Avalon Bus 暫存器映射 (Register Map)](#avalon-bus-暫存器映射-register-map)
  - [目錄](#目錄)
  - [1. 系統模組分配 (System Module Map)](#1-系統模組分配-system-module-map)
      - [模組位址映射表](#模組位址映射表)
  - [2. Serial Search 模組 (gps\_baseband\_0)](#2-serial-search-模組-gps_baseband_0)
    - [2.1 Serial Search 通道偏移量 (Channel Offset)](#21-serial-search-通道偏移量-channel-offset)
    - [2.2 Serial Search 系統狀態與控制 (Status \& Control)](#22-serial-search-系統狀態與控制-status--control)
      - [2.2.1 Serial Search Code\_Delay Group (Base: 0x0D0)](#221-serial-search-code_delay-group-base-0x0d0)
      - [2.2.2 Serial Search Status Group (Base: 0x0E0)](#222-serial-search-status-group-base-0x0e0)
      - [2.2.3 Serial Search Control Group (Base: 0x0F0)](#223-serial-search-control-group-base-0x0f0)
  - [3 Parallel Search 模組 (parallel\_search\_0)](#3-parallel-search-模組-parallel_search_0)
    - [3.1 模式定義 (Operation Modes)](#31-模式定義-operation-modes)
    - [3.2 Parallel Search暫存器 (Base: 0x400)](#32-parallel-search暫存器-base-0x400)
    - [3.3 相關值記錄 - Mode 0 (Base: 0x400)](#33-相關值記錄---mode-0-base-0x400)
    - [3.4 相關值記錄 - Mode 1 (Base: 0x400)](#34-相關值記錄---mode-1-base-0x400)
    - [3.5 相關值記錄 - Mode 2 (Base: 0x400)](#35-相關值記錄---mode-2-base-0x400)
    - [3.6 除錯資訊 (Base: 0x400)](#36-除錯資訊-base-0x400)
  - [4. MAX2769 模組 (max2769)](#4-max2769-模組-max2769)
  - [4.1 MAX2769 暫存器 (Base: 0x820)](#41-max2769-暫存器-base-0x820)
  - [5. 韌體開發範例 (C Language)](#5-韌體開發範例-c-language)

---

## 1. 系統模組分配 (System Module Map)
本專案透過 **h2f_lw_axi_master** (Lightweight HPS-to-FPGA Bridge) 進行硬體存取。在 HWLib 的 `socal/hps.h` 中定義了橋接器的物理基底位址：

```c
// 物理基底位址定義
#define ALT_LWFPGASLVS_OFST    0xff200000 
```

#### 模組位址映射表
> [!TIP]
> **位址對齊提醒**：由於是透過 Lightweight Bridge 存取，所有的位址均為 32-bit 對齊。在 C 語言中指標轉型時，請確保使用 `uint32_t *` 以符合 Avalon-MM 的存取規範。

各模組於 Avalon Bus 上的相對位址（Offset）如下。

在韌體開發時，實際存取位址為：`ALT_LWFPGASLVS_OFST + Module_Base`。

| 模組名稱 | 類別 (Class) | 基底位址 (Base) | 說明 |
| --- | --- | --- | --- |
| **Serial Search** | `gps_baseband` | `0x000` | 包含 13 個追蹤通道與系統控制暫存器 |
| **Parallel Search** | `parallel_search` | `0x400` | 平行碼相位搜尋模組 |
| **SPI Controller**  | `altera_avalon_spi` | `0x800` | 用於配置射頻端參數 |
| **MAX2769** | `max2769` | `0x820` | 射頻前端 (RF Front-end) 控制模組  |

## 2. Serial Search 模組 (gps_baseband_0)

通道區採用重複的結構。

**第 $N$ 個通道** (N=0~12)的位址計算方式為：`Target_Addr = Base (0x000) + (Channel * 0x10) + Offset`

| 區塊名稱 | 位址範圍 (Address) | 說明 |
| --- | --- | --- |
| **chan_0 ~ 12** | `0x00` - `0xCF` | 13 個獨立相關器/通道(Correlator/Channel)(每個通道佔用 16 bytes) |
| **Code Delay**  | `0xD0` - `0xDF` | Parallel Code Phase Search 相關參數 |
| **status** | `0xE0` - `0xEF` | 系統狀態暫存器 |
| **control** | `0xF0` - `0xFF` | 系統控制暫存器 |

### 2.1 Serial Search 通道偏移量 (Channel Offset)
> [!NOTE]
> 這些暫存器位於通道區（Offset <= 0xCF），為13個相關器(通道)。

| 偏移量 (Offset) | 名稱 (Name) | 權限 | 說明 |
| --- | --- | --- | --- |
| `0x0` | `prn_key` | **R/W** | 設定衛星 PRN 編碼 |
| `0x1` | `carrier_nco` | **R/W** | 載波 NCO 控制參數 |
| `0x2` | `code_nco` | **R/W** | 測距碼 NCO 控制參數 |
| `0x3` | `code_slew` | **R/W** | 測距碼相位調整 (Slew Control) |
| `0x4` | `I_early` | **R** | 同相分量 - 早 (In-phase Early) |
| `0x5` | `Q_early` | **R** | 正交分量 - 早 (Quadrature Early) |
| `0x6` | `I_prompt` | **R** | 同相分量 - 即時 (In-phase Prompt) |
| `0x7` | `Q_prompt` | **R** | 正交分量 - 即時 (Quadrature Prompt)  |
| `0x8` | `I_late` | **R** | 同相分量 - 晚 (In-phase Late) |
| `0x9` | `Q_late` | **R** | 正交分量 - 晚 (Quadrature Late) |
| `0xA` | `carrier_val` | **R** | 目前載波數值讀取 |
| `0xB` | `code_val` | **R** | 目前碼 NCO 數值讀取 |
| `0xC` | `epoch` | **R** | Epoch 計數值 (1ms 週期) |
| `0xD` | `epoch_check` | **R** | - |
| `0xE` | `epoch_load`  | **R/W** | 載入 Epoch 狀態 |
| `0xF` | `chip_select` | **R/W** | early/prompt/late之間相差多少個chip  |

### 2.2 Serial Search 系統狀態與控制 (Status & Control)
> [!NOTE]
> 這些暫存器位於通道區之後（Offset >= 0xD0），為全域控制與狀態監控使用。

#### 2.2.1 Serial Search Code_Delay Group (Base: 0x0D0)
用於對齊Parallel Code Phase結果與Serial Search 碼相位差異。

| 偏移量 (Offset)  | 名稱 (Name) | 權限 | 說明 |
| --- | --- | --- | --- |
|  `0x0` | `set_serial_ch[0]` | **R/W** | Parallel Search占用的Serial Search通道之一 |
|  `0x1` | `set_serial_ch[1]` | **R/W** | Parallel Search占用的Serial Search通道之二 |
|  `0x2` | `ch0_hc_count2_start`  | **R** | Parallel Search開始時，Serial Search 通道0的hc_count2 |
|  `0x3` | `ch0_hc_count3_start`  | **R** | Parallel Search開始時，Serial Search 通道0的hc_count3 |
|  `0x4` | `ch0_hc_count2_end` | **R** | Parallel Search結束時，Serial Search 通道0的hc_count2 |
|  `0x5` | `ch0_hc_count3_end` | **R** | Parallel Search結束時，Serial Search 通道0的hc_count3 |
|  `0x6` | `ch0_hc_count2_q` | **R** | 每0.1 [ms]中斷栓鎖通道0的hc_count2 |
|  `0x7` | `ch0_hc_count3_q` | **R** | 每0.1 [ms]中斷栓鎖通道0的hc_count3 |
|  `0x8` | `ch1_hc_count3_start`  | **R** | Parallel Search開始時，Serial Search 通道1的hc_count3 |
|  `0x9` | `ch1_hc_count3_end` | **R** | Parallel Search結束時，Serial Search 通道1的hc_count3 |
|  `0xA` | `ch1_hc_count3_q` | **R** | 每0.1 [ms]中斷栓鎖通道1的hc_count3 |
|  `0xB` | `ch2_hc_count3_start`  | **R** | Parallel Search開始時，Serial Search 通道2的hc_count3 |
|  `0xC` | `ch2_hc_count3_end` | **R** | Parallel Search結束時，Serial Search 通道2的hc_count3 |
|  `0xD` | `ch2_hc_count3_q` | **R** | 每0.1 [ms]中斷栓鎖通道2的hc_count3 |

#### 2.2.2 Serial Search Status Group (Base: 0x0E0)

| 偏移量 (Offset) | 名稱 (Name) | 權限  | 說明 |
| --- | --- | ----- | --- |
| `0x0` | `status` | **R** | 系統整體運作狀態 |
| `0x1` | `new_data` | **R** | 新數據產生標記 (Interrupt status) |
| `0x2` | `tic_count` | **R** | 系統 Tic 計時器數值 |
| `0x3` | `accum_count` | **R** | 累加器計數值 |

#### 2.2.3 Serial Search Control Group (Base: 0x0F0)

| 偏移量 (Offset) | 名稱 (Name) | 權限  | 說明 |
| --- | --- | ----- | --- |
| `0x0` | `reset` | **W** | 系統軟體復位 |
| `0x1` | `prog_tic` | **W** | 設定 Tic 週期 |
| `0x2` | `prog_accum_int` | **W** | 設定累加中斷區間 |

## 3 Parallel Search 模組 (parallel_search_0)

本模組基底位址為 **`0x400`**，專用於衛星訊號的快速擷取 (Acquisition)。

搜尋行為由 `set_mode` (Offset `0x03`) 決定，並在 `ctrl_start` (Offset `0x00`) 偵測到上升緣脈衝時鎖定參數並啟動運算。

### 3.1 模式定義 (Operation Modes)

| 模式 (Mode) | 名稱 | 搜尋範圍 | 應用場景 |
| --- | --- | --- | --- |
| **Mode 0**  | **全域搜尋模式** | 32 PRN × 41 Shifts | 遍歷所有衛星進行訊號擷取。 |
| **Mode 1**  | **局部搜尋模式** | 特定 PRN × 指定範圍 | 針對特定 PRN 進行精細搜尋。 |
| **Mode 2**  | **除錯解析模式** | 32 PRN × 41 Shifts × 4096 Data | 讀取每一筆相關性結果，每次計算後需發送 `table_data_read_ack` 才能繼續。 |

### 3.2 Parallel Search暫存器 (Base: 0x400)

| 偏移量 (Offset) | 名稱 (Name) | 權限 | 說明 |
| --- | --- | --- | --- |
| `0x00` | `ctrl_start` (W) / `ctrl` (R) | **R/W** | 寫入以啟動計算 / 讀取目前控制狀態 |
| `0x01` | `state` | **R** | 顯示目前系統主狀態機狀態 |
| `0x02` | `irq_ack` | **W** | 中斷確認 (Clear Interrupt) |
| `0x03` | `set_mode` | **R/W** | 設定運行模式 (Mode 0, 1, 2) |
| `0x04` | `set_condition` | **R/W** | 設定計算邊界條件 |
| `0x10` | `table_CDC_in_address` | **R/W** | CDC (Clock Domain Crossing) 輸入位址 |
| `0x11` | `table_CDC_out_data` | **R** | CDC 輸出數據讀取 |

### 3.3 相關值記錄 - Mode 0 (Base: 0x400)

| 偏移量 (Offset) | 名稱 (Name) | 權限 | 說明 |
| --- | --- | --- | --- |
| `0x20` | `table_in_CACode` | **R/W** | 輸入 CA Code 索引 |
| `0x21` | `table_in_shift` | **R/W** | 輸入位移量 (Shift) |
| `0x22` | `table_out_correlation_avg` | **R** | 輸出平均相關值 |
| `0x23` | `table_out_correlation` | **R** | 輸出原始相關值 |
| `0x24` | `table_out_chip_offset` | **R** | 輸出 Chip 偏移量 |
| `0x25` | `table_max_valid` | **R** | 最大值有效標記 |
| `0x26` | `table_max_in_CACode` | **R/W** | 最大值對應的 CA Code |
| `0x27` | `table_max_out_shift` | **R/W** | 最大值對應的位移量 |

### 3.4 相關值記錄 - Mode 1 (Base: 0x400)

| 偏移量 (Offset) | 名稱 (Name) | 權限 | 說明 |
| --- | --- | --- | --- |
| `0x30` | `set_CACode_id` | **R/W** | 指定要搜尋的衛星 CA Code ID |
| `0x31` | `set_shift_center` | **R/W** | 指定搜尋中心位移 |
| `0x32` | `set_shift_width`  | **R/W** | 指定搜尋寬度範圍 |

### 3.5 相關值記錄 - Mode 2 (Base: 0x400)

| 偏移量 (Offset) | 名稱 (Name) | 權限 | 說明 |
| --- | --- | --- | --- |
| `0x40` | `table_data_in_index` | **R/W** | 除錯數據索引輸入 |
| `0x41` | `table_data_out_CACode` | **R** | 輸出當前除錯的 CA Code |
| `0x42` | `table_data_out_shift` | **R** | 輸出當前除錯的位移量 |
| `0x43` | `table_data_out_correlation` | **R** | 輸出當前除錯的相關值 |
| `0x44` | `table_data_read_ack` | **W** | 除錯數據讀取確認 (用於進入下一個數據點) |

### 3.6 除錯資訊 (Base: 0x400)
| 偏移量 (Offset) | 所屬模組 | 名稱 (Name) | 權限  | 說明 |
| --- | --- | --- | ----- | ---- |
| `0x50` | `correlation_processing` | `CACode` | **R** | |
| `0x51` | `correlation_processing` | `shift_unsigned` | **R** | |
| `0x52` | `correlation_processing` | `shift_end_unsigned` | **R** | |
| `0x53` | `correlation_processing` | `cnt_data` | **R** | |
| `0x54` | `controller_ft_input` | `state` | **R** | |
| `0x55` | `controller_ft_input` | `cnt_FTIn` | **R** | |
| `0x56` | `convolution` | `state` | **R** | |
| `0x57` | `CACode_generator` | `state` | **R** | |
| `0x58` | `CACode_generator` | `cnt_data` | **R** | |

## 4. MAX2769 模組 (max2769) 
本模組基底位址為 **`0x820`**，主要負責管理 MAX2769 晶片的電源狀態與監測硬體連接狀態。透過此模組，韌體端可以確保 RF 前端模組已正確啟動且時脈穩定，這是衛星訊號擷取的前提條件。

## 4.1 MAX2769 暫存器 (Base: 0x820)
| 偏移量 (Offset) |  名稱 (Name) | 權限 | 說明 |
| --- | --- | --- | --- |
|  **0x0** | `IDLE_B` | **R/W**  | **空閒模式控制**：設定為 `1` 進入正常工作模式，`0` 進入待機模式。 |
|  **0x0** | `IDLE_B` | **R/W**  | **硬體關斷控制**：設定為 `1` 開啟晶片，`0` 關閉晶片電源 (Shutdown)。 |
|  **0x0** | `is_frontend_connected` | **R** | **物理連接偵測**：`1` 代表 Front-end 模組已正確插入 GPIO，`0` 為未連接。 |
|  **0x0** | `clk_frontend_locked` | **R** | **時脈鎖定監測**：讀取 MAX2769 內部 PLL 狀態。`1`: 時脈鎖定且穩定 (Locked)，`0`: 未鎖定 (Unlocked)。 |

> [!CAUTION]
> **啟動順序建議**：在進行任何搜尋 (Acquisition) 動作前，請務必先確認 `is_frontend_connected` 與 `clk_frontend_locked` 皆為 `1`，以確保採樣到的訊號為有效衛星數據。

## 5. 韌體開發範例 (C Language)
檔案位置`firmware/hps_core/DE10_serial_parallel/INC/namuru.h`，存取範例如下：
```c
ch_block->channels[0].chip_select = 1; // 設定通道 0的early/prompt/late之間相差0.25 [chip]
```

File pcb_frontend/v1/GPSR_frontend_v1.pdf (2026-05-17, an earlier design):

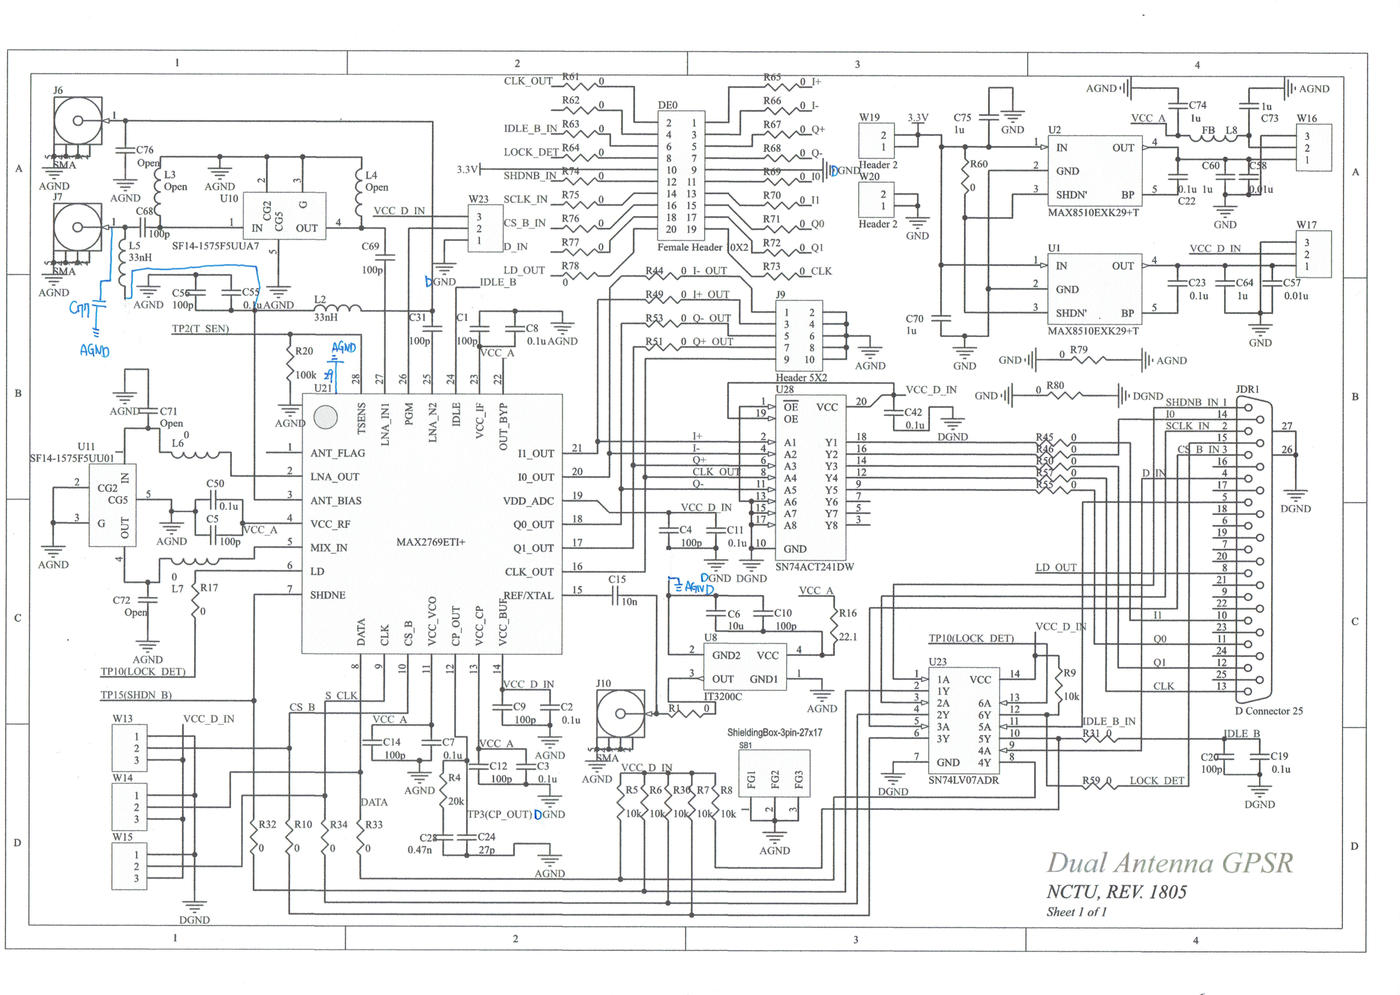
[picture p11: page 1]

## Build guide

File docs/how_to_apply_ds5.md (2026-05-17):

# 如何申請 DS-5 / Arm DS 開發環境 (TSRI 資源)

本文件說明如何透過 **TSRI (台灣半導體研究中心)** 申請本專案所需的開發工具授權。

> [!IMPORTANT]
> **申請前提**：您必須具備 **TSRI 有效會員資格**。若非會員，將無法存取受保護的軟體授權。

## 注意事項 (Notice)
1. **並行處理**：主要流程（TSRI 申請與 DNS 申請）可同時進行，兩者皆完成後方可連線授權。
2. **網路驗證**：TSRI 的 License Server 需驗證申請設備之 IP 是否具備「正反查 (Forward/Reverse DNS Lookup)」能力。

## 主要流程
1. **TSRI 申請 EDA Tools 授權**
2. **校園/單位 DNS 申請正反查登錄**

## 詳細申請步驟

### 1. TSRI 申請 EDA Tools
- **註冊帳號**：請至 [TSRI 會員服務平台](https://www.tsri.org.tw/) 註冊或確認您的會員身分。
- **軟體申請**：依照 [TSRI EDA tools 申請流程](https://www.tsri.org.tw/main.jsp) 辦理。
- **IP 登錄**：完成申請後，需於 TSRI 平台登錄您的設備公網 IP。
- **軟體取得**：
  - 登入後至：軟體資訊 > Embedded Software > DS。
  - 下載對應版本並依照 `Installation_Guide` 進行安裝。

### 2. 校園 DNS 正反查申請 (以 NYCU 為例)
由於 TSRI 伺服器安全性要求，您的 IP 必須綁定 Domain Name。
- **連線系統**：進入 [NYCU DNS 服務申請系統](https://dns.nycu.edu.tw/)。
- **功能選單**：點選 `網域名稱登錄` 並接受管理規範。
- **填寫基本資料**：
  - **主管資訊**：請填寫您的指導教授 姓名、工號與電郵。
- **申請細節**：
  - **託管期限**：建議選擇 3 年（視研究需求而定）。
  - **單位**：選擇您的所屬實驗室。

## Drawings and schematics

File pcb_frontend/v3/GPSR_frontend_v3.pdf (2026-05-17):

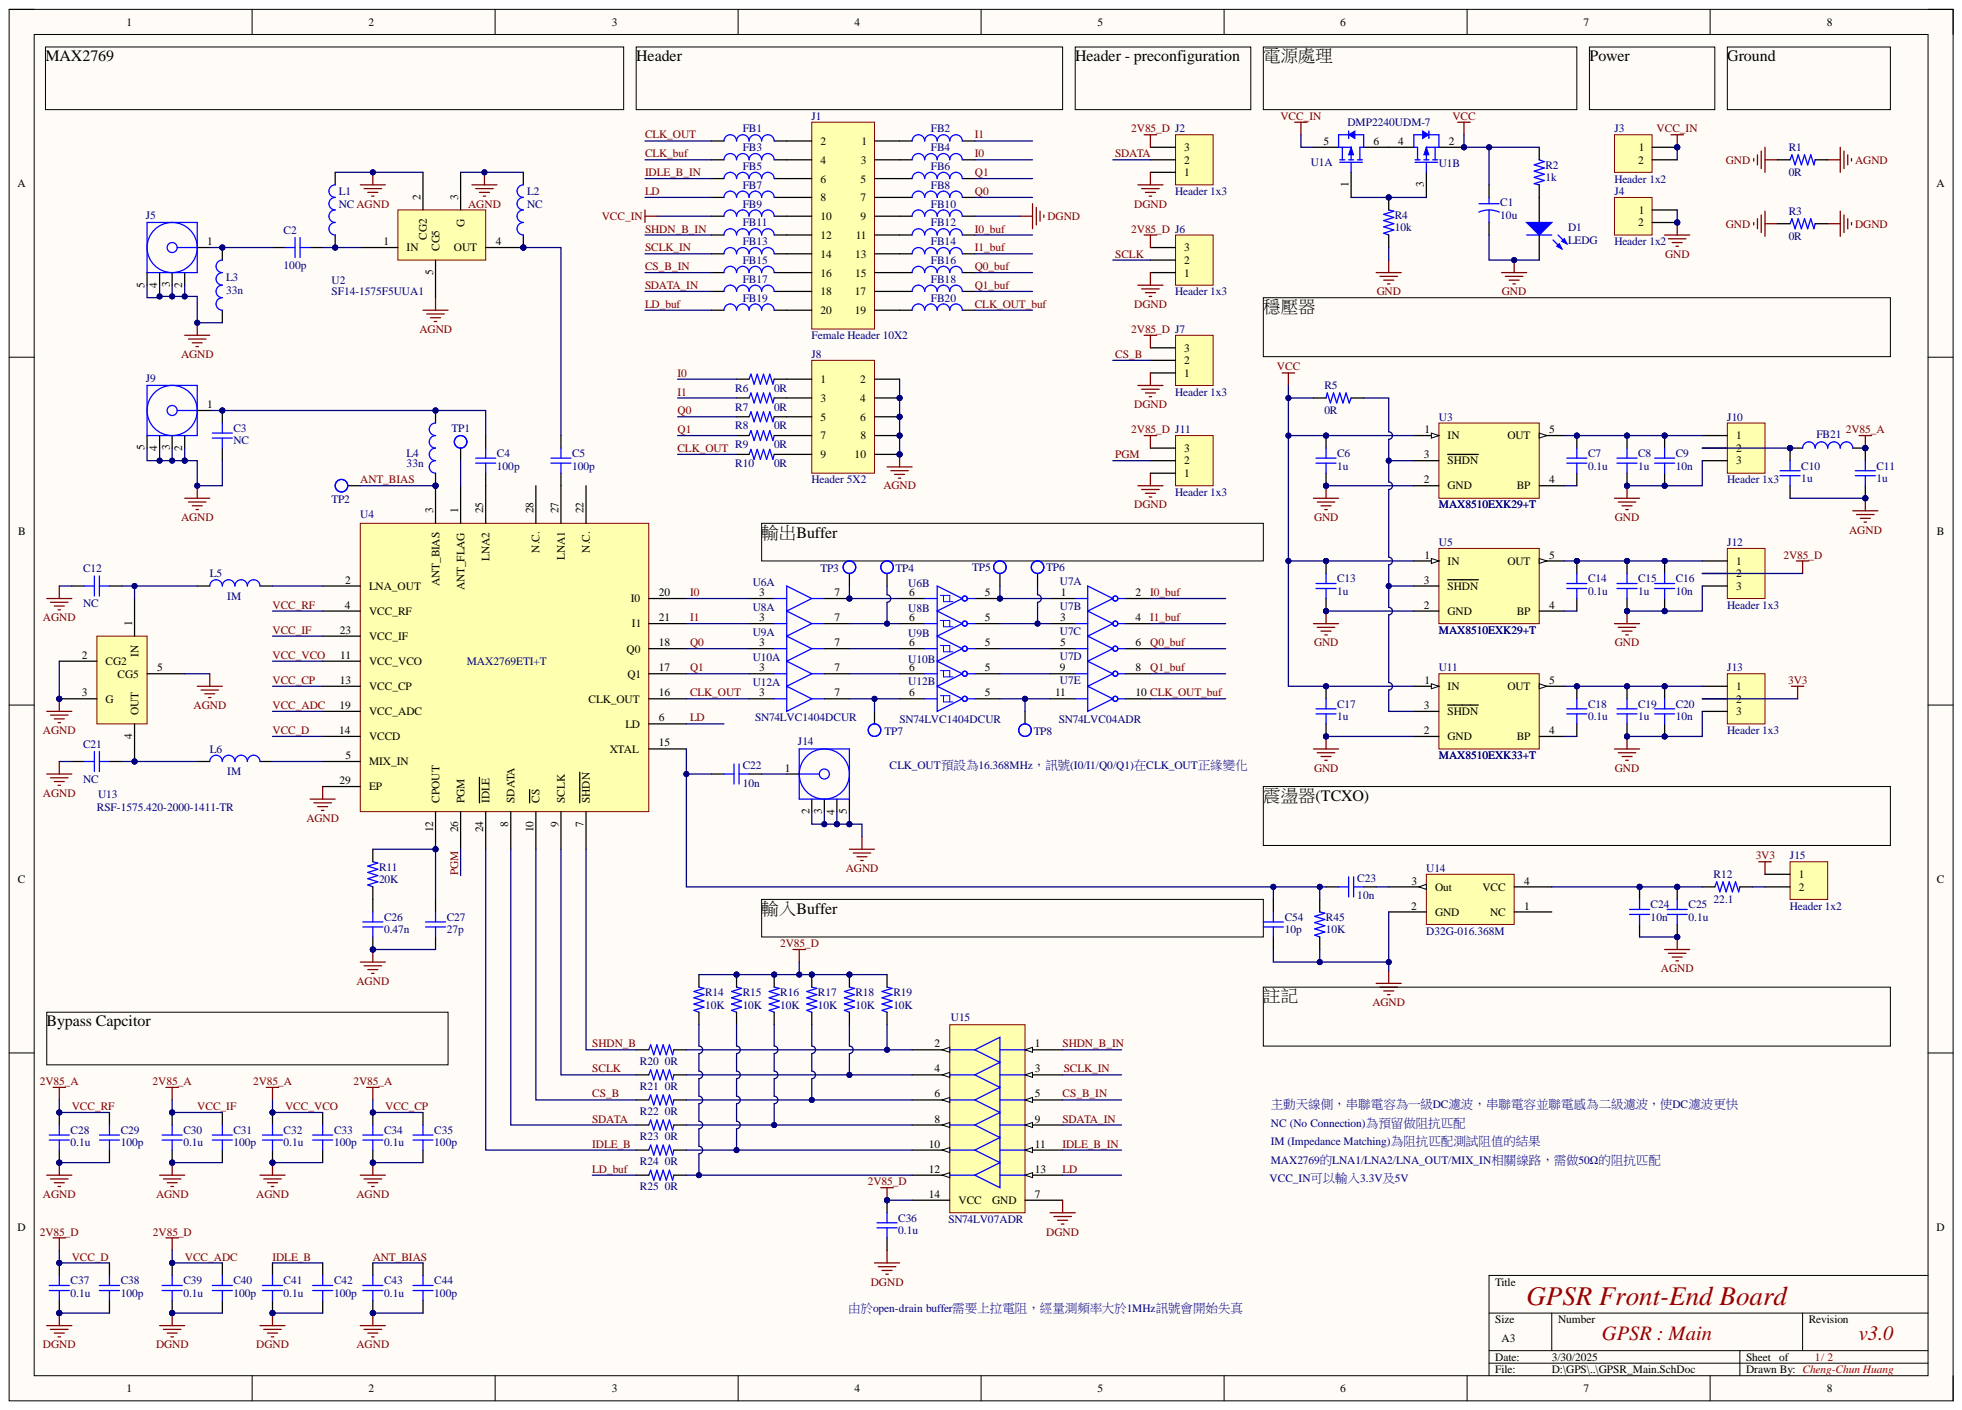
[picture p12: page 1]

主動天線側，串聯電容為一級DC濾波，串聯電容並聯電感為二級濾波，使DC濾波更快
NC (No Connection)為預留做阻抗匹配
IM (Impedance Matching)為阻抗匹配測試阻值的結果
MAX2769的LNA1/LNA2/LNA_OUT/MIX_IN相關線路，需做50Ω的阻抗匹配
VCC_IN可以輸入3.3V及5V

Title
GPSR Front-End Board

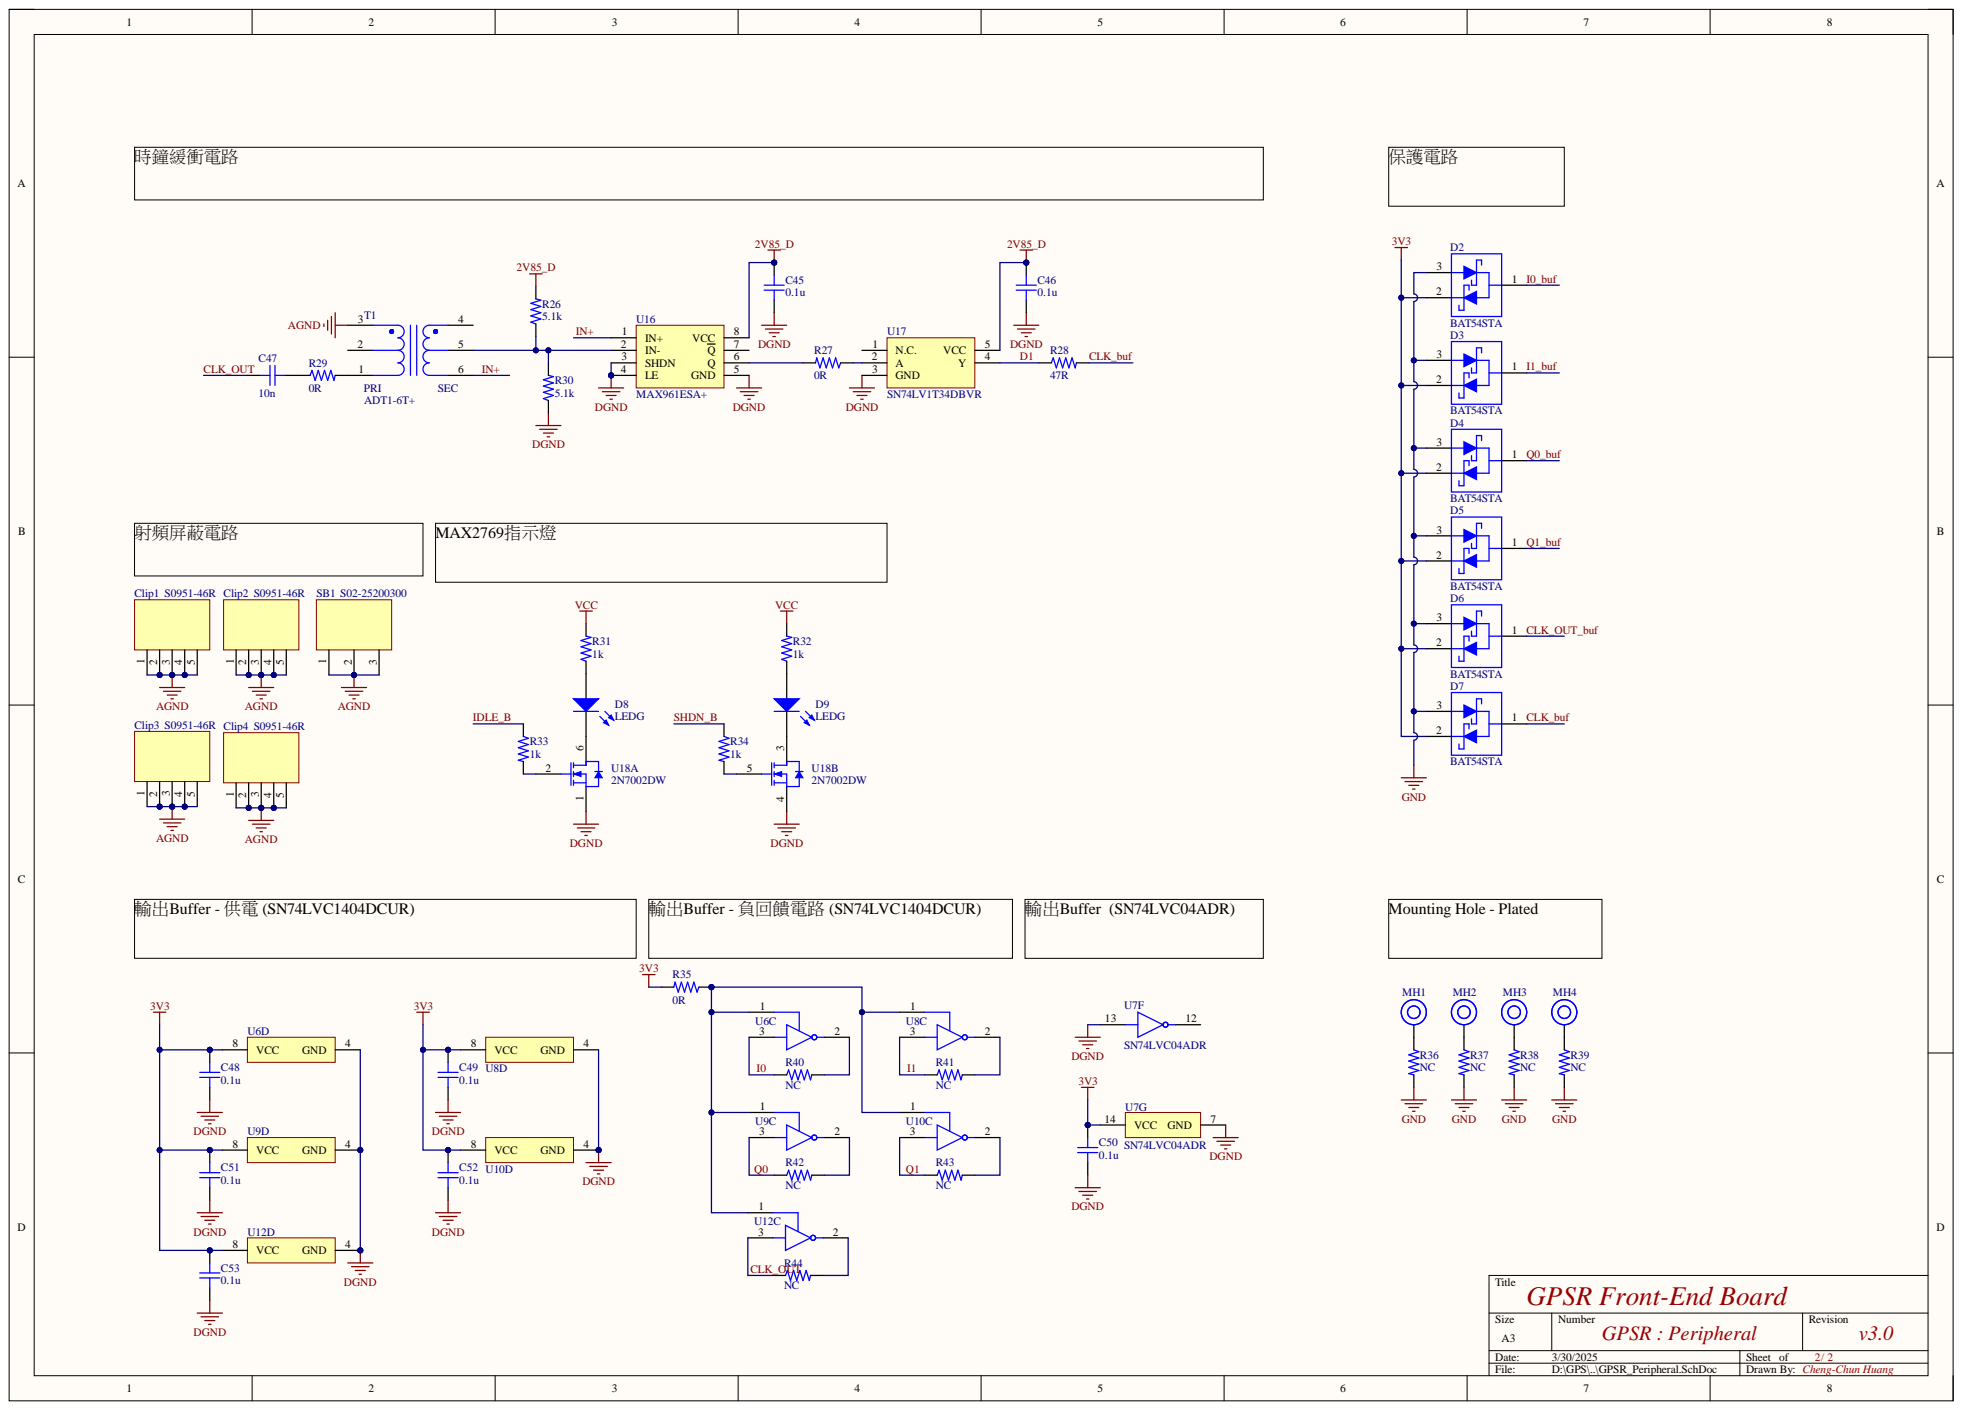
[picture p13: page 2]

Title
GPSR Front-End Board

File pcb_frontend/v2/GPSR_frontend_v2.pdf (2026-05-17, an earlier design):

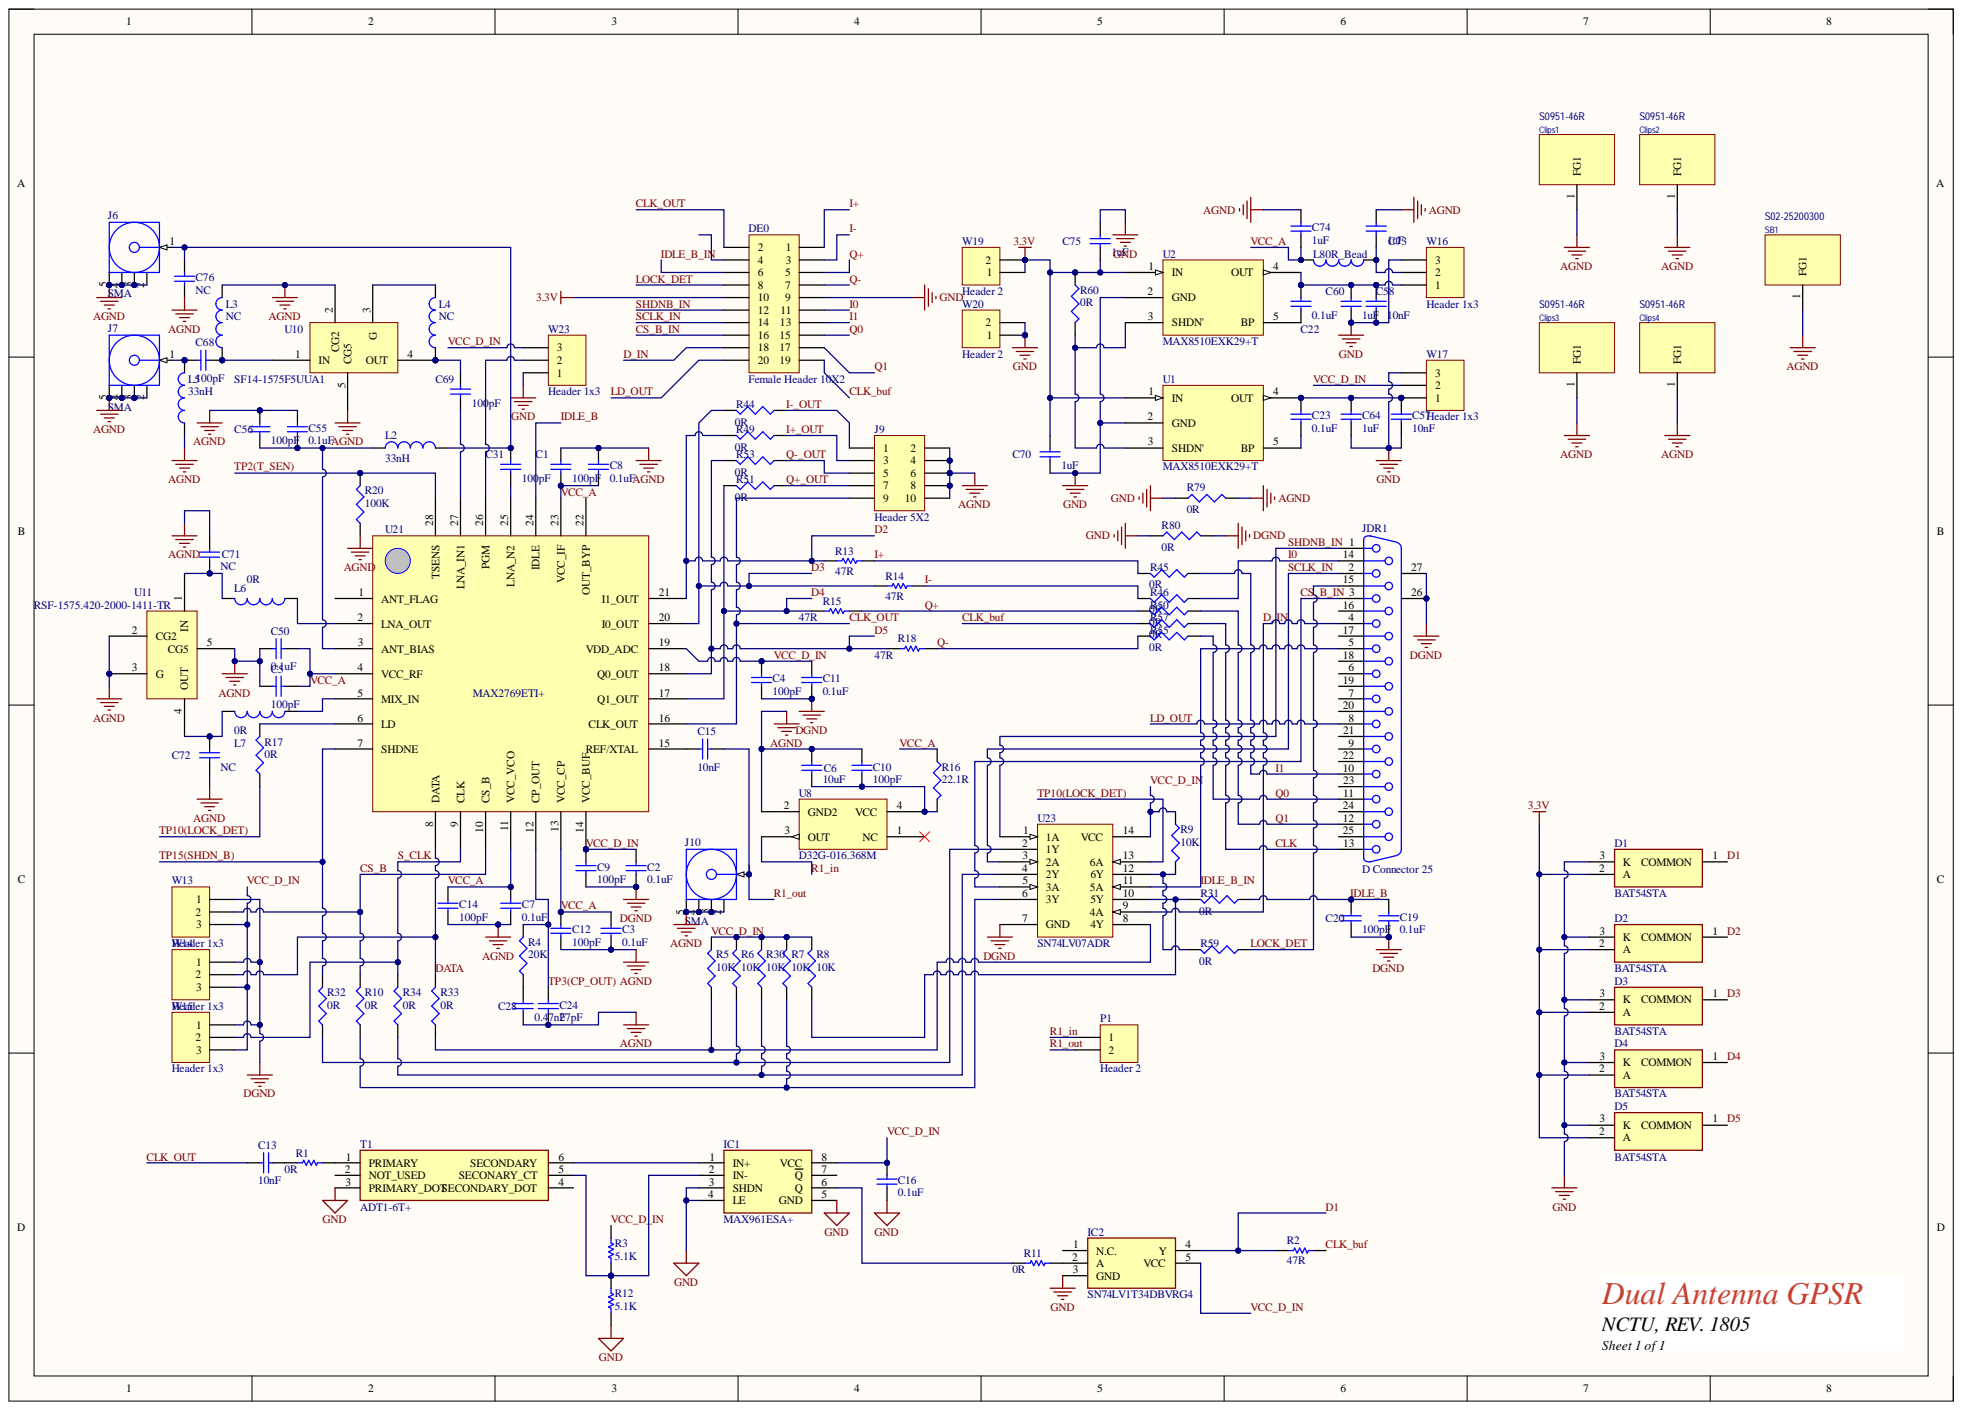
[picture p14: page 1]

GND 7 3A 5 | 8 4A 9 5Y 10 5A 11 6Y 12 6A 13

Dual Antenna GPSR
NCTU, REV. 1805 Sheet 1 of 1

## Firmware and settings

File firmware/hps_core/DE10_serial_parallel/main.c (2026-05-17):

#include "cmsis_os2.h"
#include "RTE_Components.h"
#include CMSIS_device_header

#include "max2769.h"
#include "parallel_search.h"
#include "tracking.h"
#include "allocate.h"
#include "namuru.h"
#include "display.h"
#include "message.h"
#include "ephemeris.h"
#include "measure.h"
#include "position.h"
#include "uart.h"
#include "irq_ctrl.h" // Generic Interrupt Controller
#include <stdio.h>
#include <stdint.h>

osThreadId_t allocate_thread_id;
osThreadId_t display_thread_id;
osThreadId_t message_thread_id;
osThreadId_t measure_thread_id;
osThreadId_t tick_capture_thread_id;
osThreadId_t parallel_search_thread_id;
osThreadId_t parallel_search_debug_thread_id;


const osThreadAttr_t allocate_thread_attr = {
    .name = "allocate_thread",
    .priority = osPriorityAboveNormal,
    .stack_size = 2048};

const osThreadAttr_t display_thread_attr = {
    .name = "display_thread",
     .priority = osPriorityNormal,
    .stack_size = 2048};

const osThreadAttr_t message_thread_attr = {
    .name = "message_thread",
    .priority = osPriorityHigh,
    .stack_size = 2048};

const osThreadAttr_t measure_thread_attr = {
    .name = "measure_thread",
    .priority = osPriorityRealtime,
    .stack_size = 4096};

const osThreadAttr_t parallel_search_thread_attr = {
    .name = "parallel_search_thread",
    .priority = osPriorityAboveNormal,
    .stack_size = 2048};

const osThreadAttr_t tick_capture_thread_attr = {
    .name = "tick_capture_thread",
    .priority = osPriorityHigh,
    .stack_size = 2048};

void app_main()
{
    // Initialize frontend
    max2769_init();

    // Enable UART0 RX Interrupt
    uart0_init();

    // Display warning info - if you only program ARM CPU but not FPGA device
    display_startup_info();

#if (ACQ_MODE_SYSTEM == ACQ_MODE_SERIAL)
    initialize_allocation();
#endif
    control_block->prog_tic = 4999999;     // 0.1 [s]  update FPGA system
    control_block->prog_accum_int = 24999; // 0.5 [ms] update accumulator

    // Setup Interrupt Handler - received interrupt from FPGA
    IRQ_SetHandler(FPGA_IRQ0, tracking_IRQ); // Set level-sensitive (and N-N model)
    IRQ_SetHandler(FPGA_IRQ1, parallel_search_IRQ); // Set level-sensitive (and N-N model)
    // Setup Interrupt Handler - received interrupt from keyboard input (UART0 RX)
    IRQ_SetHandler(UART0_IRQ, set_display_command); // Set level-sensitive (and N-N model)
    
    IRQ_Enable(FPGA_IRQ0);
    IRQ_Enable(FPGA_IRQ1);
    IRQ_Enable(UART0_IRQ);
}

int main(void)
{
    // MPU Clock: 925 MHz (Configured by Preloader)
    // Private Timer Clock (mpu_periph_clk): 231.250 MHz (MPU Clock divided by 4)
    // Reference: Cyclone V Hard Processor System Technical Reference Manual
    SystemCoreClockUpdate();
    osKernelInitialize();
    allocate_thread_id = osThreadNew((osThreadFunc_t)allocate_thread, NULL, &allocate_thread_attr);
    display_thread_id  = osThreadNew((osThreadFunc_t)display_thread, NULL, &display_thread_attr);
    message_thread_id  = osThreadNew((osThreadFunc_t)message_thread, NULL, &message_thread_attr);
    measure_thread_id  = osThreadNew((osThreadFunc_t)measure_thread, NULL, &measure_thread_attr);
    tick_capture_thread_id = osThreadNew((osThreadFunc_t)tick_capture_thread, NULL, &tick_capture_thread_attr);
#if (ACQ_MODE_SYSTEM == ACQ_MODE_HYBRID)
    parallel_search_thread_id = osThreadNew((osThreadFunc_t)parallel_search_thread, NULL, &parallel_search_thread_attr);
    // parallel_search_debug_thread_id = osThreadNew((osThreadFunc_t)parallel_search_debug_thread, NULL, NULL);
#endif
    osThreadNew((osThreadFunc_t)app_main, NULL, NULL);
    osKernelStart();

    while (1)
        ;
}

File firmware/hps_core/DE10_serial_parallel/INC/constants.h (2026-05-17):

// constants.h: Header file for various SHARED constants
// Copyright (C) 2005  Andrew Greenberg
// Distributed under the GNU GENERAL PUBLIC LICENSE (GPL) Version 2 (June 1991).
// See the "COPYING" file distributed with this software for more information.

#ifndef __CONSTANTS_H
#define __CONSTANTS_H

// GPS Constellation
#define N_SATELLITES 32
#define TIC_PERIOD 0.1 // This is the default = (100ms - 100ns)

// RF Timing
#define GPS_REF 10.23E6    /* theoretical GPS reference frequency [Hz] */
#define L1 (154 * GPS_REF) /* nominal civilian GPS satellite \
                              carrier frequency, 1.57542GHz */

// Code NCO timing
#define CODE_NCO_LENGTH 1024
#define CODE_PERIOD 1023                 // Gold code period
#define MAX_CODE_PHASE (2 * CODE_PERIOD) // In half-chips
#define CHIP_RATE (GPS_REF / 10)
#define HALF_CHIP_RATE (2 * CHIP_RATE)
#define CODE_TIME (CODE_PERIOD / CHIP_RATE)  // 1ms precisely
#define QUARTER_CHIP_TIME (0.25 / CHIP_RATE) // about 74[m]

// GPS Week Defines
#define SECONDS_IN_WEEK (7 * 24 * 3600)     // (604800) seconds per week
#define BITS_IN_WEEK (50 * SECONDS_IN_WEEK) // (30240000) gps 50Hz data rate

// Physical Constants
#define SPEED_OF_LIGHT 2.99792458E8 // [m/s]
#define PI 3.141592653589793
#define PI_OVER_2 (PI / 2.0)
#define TWO_PI (PI * 2.0)
#define RADTODEG 180.0 / PI // [deg/r]

#endif // __CONSTANTS_H

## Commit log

2026-05-17 initial commit: complete GPS SoC platform with accelerated parallel acquisition RTL and HPS firmware
    [GPSR_Main.SchDoc, GPSR_Peripheral.SchDoc, GPSR_v2.PcbDoc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]
2026-05-18 docs: optimize README structure and update RTE Linguist filter rules
2026-05-18 feat: add compile-time acquisition mode switch and synchronize documentation
